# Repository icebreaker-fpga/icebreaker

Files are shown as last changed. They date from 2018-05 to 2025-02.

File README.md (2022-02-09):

# iCEBreaker FPGA

 

The iCEBreaker FPGA board is a low cost, open-source educational FPGA
development board.

The main motivating application of this board is for classes and workshops
teaching the use of the open source FPGA design flow using
[Yosys](http://www.clifford.at/yosys/),
[nextpnr](https://github.com/YosysHQ/nextpnr),
[icestorm](http://www.clifford.at/icestorm/),
[iverilog](http://iverilog.icarus.com/),
[symbiflow](https://github.com/SymbiFlow) and others. This means the board has
to be low cost and have a nice set of features to allow for the design of
interesting classes and workshop exercises. At the same time we want to allow
the user to use the proprietary vendor tools if they choose to. Because of that
we need to be compatible with their firmware upload tools.

## iCEBreaker Hardware Specifications

* iCE40UP5K in QFN48 (SG48) package
  * [iCE40 UltraPlus 5K](http://www.latticesemi.com/-/media/LatticeSemi/Documents/DataSheets/iCE/iCE40-UltraPlus-Family-Data-Sheet.ashx)
  * 5280 Logic Cells (4-LUT + Carry + FF)
  * 128 KBit Dual-Port Block RAM
  * 1 MBit (128 KB) Single-Port RAM
  * PLL, Two SPI and two I2C hard IPs
  * Two internal oscillators (10 kHz and 48 MHz)
  * 8 DSPs (16x16 multiply + 32 bit accumulate)
  * 3x 24mA drive and 3x hard PWM IP

* QSPI-DDR-capable flash 128 MBit (16 MB)
  * We selected to use the Winbond
    [W25Q128JVSIM](http://www.winbond.com/resource-files/w25q128jv_dtr%20revc%2003272018%20plus.pdf)
  * We want to enable projects that access the flash and we want to provide the
    highest flash access speed possible.

* [FT2232H](http://www.ftdichip.com/Support/Documents/DataSheets/ICs/DS_FT2232H.pdf) interface (microUSB plug)
  * programming compatible with iCEstick and HX8K board
    * works with [Dimond Programmer](http://www.latticesemi.com/programmer) and
      [iceprog](https://github.com/cliffordwolf/icestorm/tree/master/iceprog)
  * serial port compatible with iCEstick and HX8K breakout board
  * 12 MHz XTAL oscillator (shared with FPGA)
  * Solder jumpers to offer direct SRAM programming (like on HX8K breakout board)

* 39 I/O capable pins:
  * 4 pins for config (SDI, SDO, SCK, CSB)
    * Either loading config from on board FLASH chip or provided through the
      FTDI chip with direct SRAM config.
  * 2 extra GPIO pins for QSPI
    * Together with the config pins, allows storage of additional data in the
      FLASH chip, and high speed QSPI DDR access. For example
      [picosoc](https://github.com/cliffordwolf/picorv32/tree/master/picosoc)
      firmware.
  * 3 PINs for RGB LED (pin header)
  * 2 LEDs (one on output-only PLL pin)
  * 1 Clock pin (on PLL GBIN)
  * 1 UART Rx Pin via FTDI
  * 1 UART Tx Pin via FTDI
  * 1 Push Button
  * 16 PINs on dual PMOD
  * 8 PINs on single PMOD / snap-off section

* Support for FTDI Async FIFO mode
  * We want to support FTDI Async mode via some (unpopulated by default) zero
    ohm resistors
  * This shares 8 GPIOs with the single PMOD / snap-off section
  * This would also enable use of full list of RS232 signals
  * BDATA[0] -- Tx on FTDI / Rx on FPGA (always connected, no zohm resistor
    required)
  * BDATA[1] -- Rx on FTDI / Tx on FPGA (always connected, no zohm resistor
    required)
  * BDATA[7:2] -- Shared with snap-off section (via zohm resistor footprint)
  * RX Full -- Shared with snap-off section (via zohm resistor footprint)
  * TX Empty -- Shared with snap-off section (via zohm resistor footprint)
  * Read -- Shared with LED 1 (via zohm resistor footprint, LED used as RX
    indicator)
  * Write -- Shared with LED 2 (via zohm resistor footprint, LED used as TX
    indicator)
  * WakeUp -- Shared with Push Button (via zohm resistor footprint)
  * This configuration uses the following pins when the jumpers ore reconfigured:
    * The two on board red and green LED pins
    * The on board user button pin
    * snap off section single PMOD pins 

* Snap-off section (convertible to PMOD host / PMOD device)
  * 5 LEDs in similar arrangement to iCEstick
  * 3 Push Buttons

* Other stuff
  * Status LEDs for Power and CDONE (Configuration DONE)
  * Header with supply rails: 5V, 3V3, 1V2, GND
  * Debug header for all 6 QSPI pins
  * Test points for UART Rx / Tx signals
  * Jumpers or zohm resistors on all rails for measuring currents
  * Four 3mm mounting holes on the main section and two more on the snap-off
    section
  * The two LEDs on the main section should be wired "active low" so they work 
    well as indicator LEDs for FIFO read/write.
  * The five LEDs on the snap-off section should be wired "active high"
  * A zohm resistor for Bank 2 supply so that the IO voltage can be changed. Use
    Bank 2 for one of the ports on the double PMOD.
  * There should be auxilary 5V pin headers available for the PMODs. Some PMOD
    need either higher voltage or need to regulate their own voltage from 5V.

* Unpopulated parts shipped with the board
  * 3x Host PMOD (2x for dual PMOD port, 1x for snap-off section)
  * 1x Device PMOD (for other side of snap-off section)

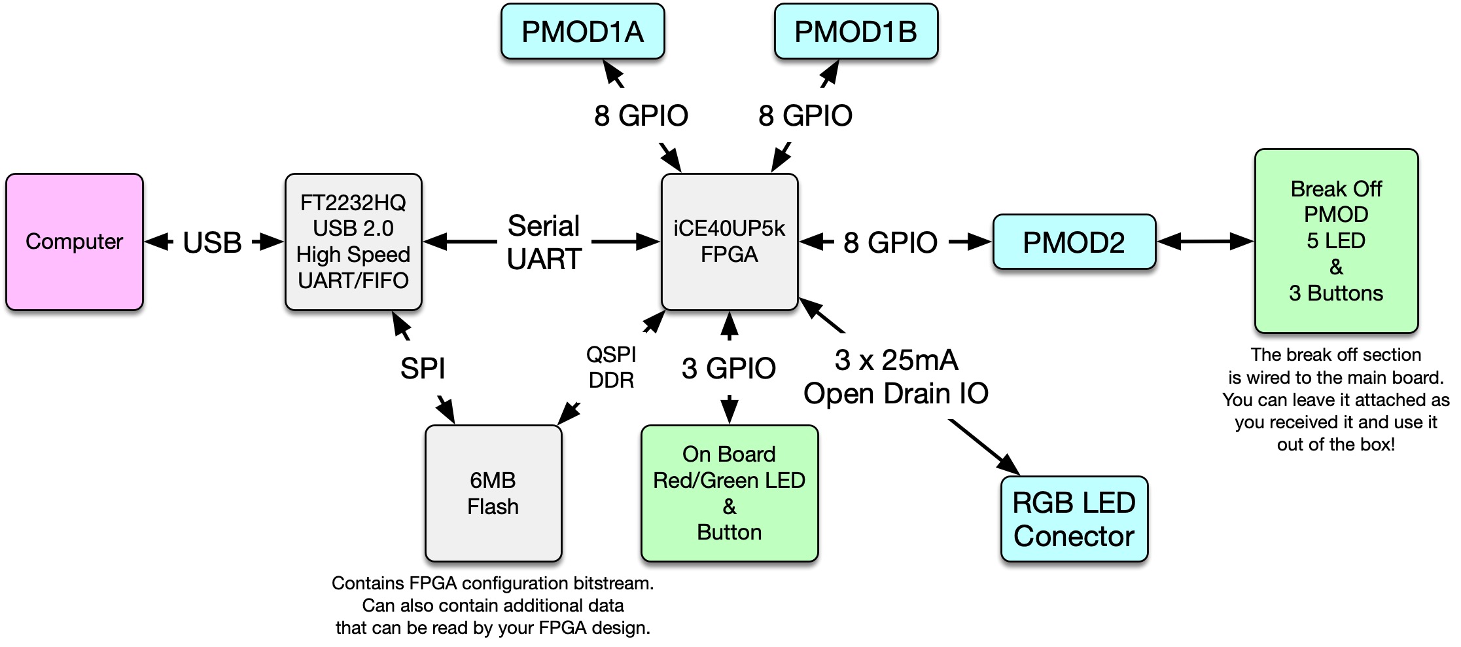
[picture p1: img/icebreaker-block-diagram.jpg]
iCEBreaker block diagram

**iCEBreaker block diagram**  
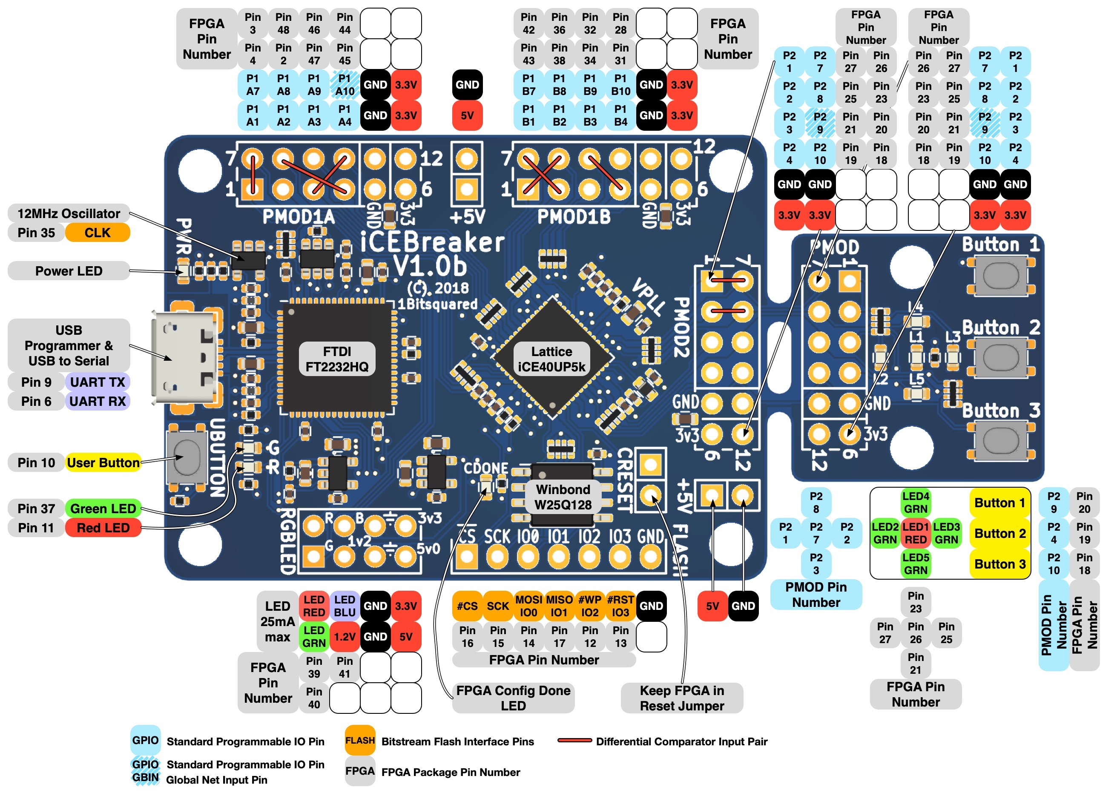
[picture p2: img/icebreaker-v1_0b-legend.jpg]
iCEBreaker V1.0b pinout legend

**iCEBreaker V1.0b pinout legend**  
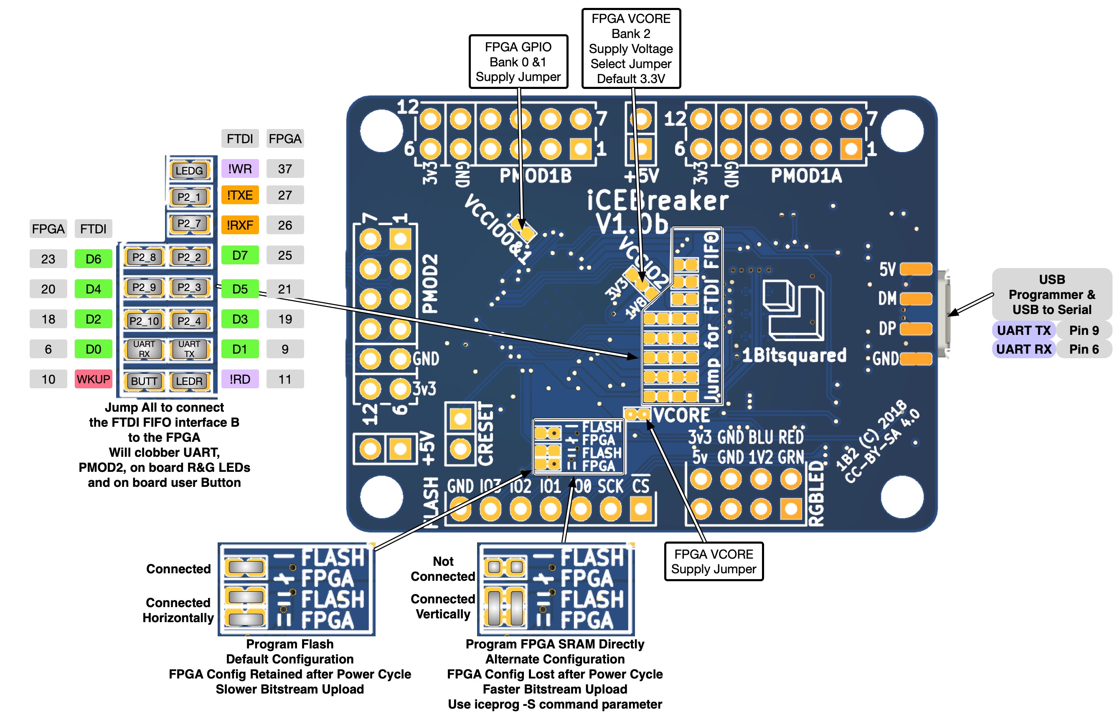
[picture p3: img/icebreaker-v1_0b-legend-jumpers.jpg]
iCEBreaker V1.0b jumper legend

**iCEBreaker V1.0b jumper legend**  

## iCEBreaker Bitsy

iCEBreaker Bitsy is the smaller but just-as-capable sibling to iCEBreaker. At just 36x18mm, it is compatible with the Teensy form-factor and can be easily embedded into any project.

iCEBreaker Bitsy v1.1b panel photo

* iCE40UP5K in QFN48 (SG48) package
  * PLL, two SPI and two I2C hard IPs
* 128M (16MiB) DDR- and QPI-capable Flash Memory
* 64M (8MiB) QPI-capable Pseudo-SRAM
* USB-C interface (comes preloaded with a [RISC-V soft-core USB bootloader](//github.com/no2fpga/no2bootloader))
* RGB LED connected to 3x 24mA hard PWM IP pins
* Two user LEDs (one shared with RAM-CS)
* Status LED for CDONE (Configuration DONE)
* 12MHz external clock (on PLL GBIN)
* One user button
* Supply rails: 3.3V and 1.2V
* FPGA SPI/programming header
  * 4 pins for config (SDI, SDO, SCK, CS)
  * 2 extra GPIO pins for QSPI/QPI
  * CDONE (Configuration DONE), CRESET (Configuration RESET), 3.3V, and GND
* Teensy form-factor compatible
* Compatible with Feather ecosystem using a [Teensy 3.x Feather Adapter](//adafruit.com/product/3200)
* Castellated edges and single-side-load for easy module integration

iCEBreaker Bitsy v1.1c info card, front
iCEBreaker Bitsy v1.1c info card, back

## Branding

[iCEbreaker](https://twitter.com/AboveVacant/status/948323920595308545)

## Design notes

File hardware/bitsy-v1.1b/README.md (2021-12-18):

# iCEBreaker Bitsy v1.1b

[Available at 1BitSquared](//1bitsquared.com/collections/fpga/products/icebreaker-bitsy)

iCEBreaker Bitsy is the smaller but just-as-capable sibling to iCEBreaker. At just 36x18mm, it is compatible with the Teensy form-factor and can be easily embedded into any project.

iCEBreaker Bitsy v1.1b panel photo

## Features
  
* iCE40UP5K in QFN48 (SG48) package
  * PLL, two SPI and two I2C hard IPs
* 128M (16MiB) DDR- and QPI-capable Flash Memory
* 64M (8MiB) QPI-capable Pseudo-SRAM
* USB-C interface (comes preloaded with a [RISC-V soft-core USB bootloader](//github.com/no2fpga/no2bootloader))
* RGB LED connected to 3x 24mA hard PWM IP pins
* Two user LEDs (one shared with RAM-CS)
* Status LED for CDONE
* 12MHz external clock (on PLL GBIN)
* One user button
* Supply rails: 3.3V and 1.2V
* FPGA SPI/programming header
  * 4 pins for config (SDI, SDO, SCK, CS)
  * 2 extra GPIO pins for QSPI/QPI
  * CDONE, CRESET, 3.3V, and GND
* Teensy form-factor compatible
* Compatible with Feather ecosystem using a [Teensy 3.x Feather Adapter](//adafruit.com/product/3200)
* Castellated edges and single-side-load for easy module integration

iCEBreaker Bitsy v1.1b info card, front
iCEBreaker Bitsy v1.1b info card, back

## Changelog

### v1.1b (2020-10-19)

* Changed board dimensions to metric instead of imperial (36x18mm)
* Added top-side silkscreen labels
* Enlarged USB-C solder paste openings

### v1.1a (2020-08-05)

* Switched to WSON 6x5mm flash to accommodate through-hole programming header
* Improved silkscreen

### v1.0a (2020-06-10)

* Complete redesign
* Pinout/dimensions now Teensy-compatible
* Moved Pseudo-SRAM to the top, populate it by default

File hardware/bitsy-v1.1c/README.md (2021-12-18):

# iCEBreaker Bitsy v1.1c

[Available at 1BitSquared](//1bitsquared.com/collections/fpga/products/icebreaker-bitsy)

iCEBreaker Bitsy is the smaller but just-as-capable sibling to iCEBreaker. At just 36x18mm, it is compatible with the Teensy form-factor and can be easily embedded into any project.

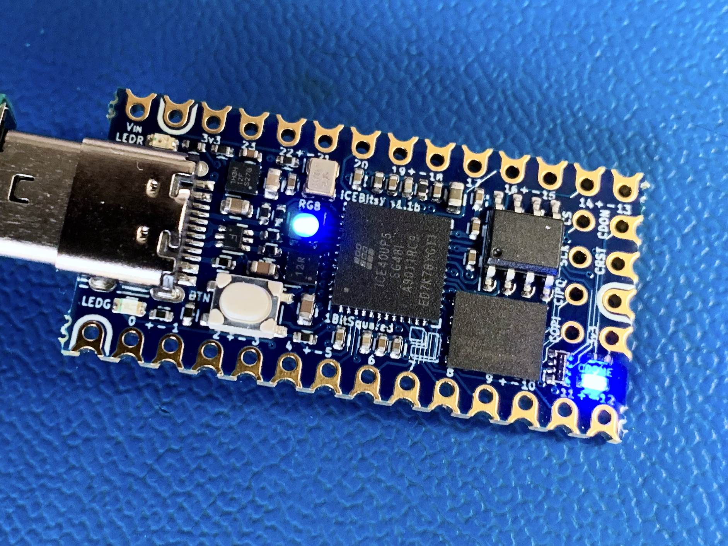
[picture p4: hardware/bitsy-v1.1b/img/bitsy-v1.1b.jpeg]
iCEBreaker Bitsy v1.1b photo


## Features
  
* iCE40UP5K in QFN48 (SG48) package
  * PLL, two SPI and two I2C hard IPs
* 128M (16MiB) DDR- and QPI-capable Flash Memory
* 64M (8MiB) QPI-capable Pseudo-SRAM
* USB-C interface (comes preloaded with a [RISC-V soft-core USB bootloader](//github.com/no2fpga/no2bootloader))
* RGB LED connected to 3x 24mA hard PWM IP pins
* Two user LEDs (one shared with RAM-CS)
* Status LED for CDONE
* 12MHz external clock (on PLL GBIN)
* One user button
* Supply rails: 3.3V and 1.2V
* FPGA SPI/programming header
  * 4 pins for config (SDI, SDO, SCK, CS)
  * 2 extra GPIO pins for QSPI/QPI
  * CDONE, CRESET, 3.3V, and GND
* Teensy form-factor compatible
* Compatible with Feather ecosystem using a [Teensy 3.x Feather Adapter](//adafruit.com/product/3200)
* Castellated edges and single-side-load for easy module integration

iCEBreaker Bitsy v1.1c info card, front
iCEBreaker Bitsy v1.1c info card, back

## Changelog

### v1.1c (2021-06-28)

* Added solder pads for USB-C SBU and CC pins
* Improved back side silkscreen

### v1.1b (2020-10-19)

* Changed board dimensions to metric instead of imperial (36x18mm)
* Added top-side silkscreen labels
* Enlarged USB-C solder paste openings

### v1.1a (2020-08-05)

* Switched to WSON 6x5mm flash to accommodate through-hole programming header
* Improved silkscreen

### v1.0a (2020-06-10)

* Complete redesign
* Pinout/dimensions now Teensy-compatible
* Moved Pseudo-SRAM to the top, populate it by default

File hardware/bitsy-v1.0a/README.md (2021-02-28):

# iCEBreaker Bitsy v1.0a

[Available at 1BitSquared](//1bitsquared.com/collections/fpga/products/icebreaker-bitsy)

iCEBreaker Bitsy is the smaller but just-as-capable sibling to iCEBreaker. At just 1.4x0.7in, it is compatible with the Teensy form-factor and can be easily embedded into any project.

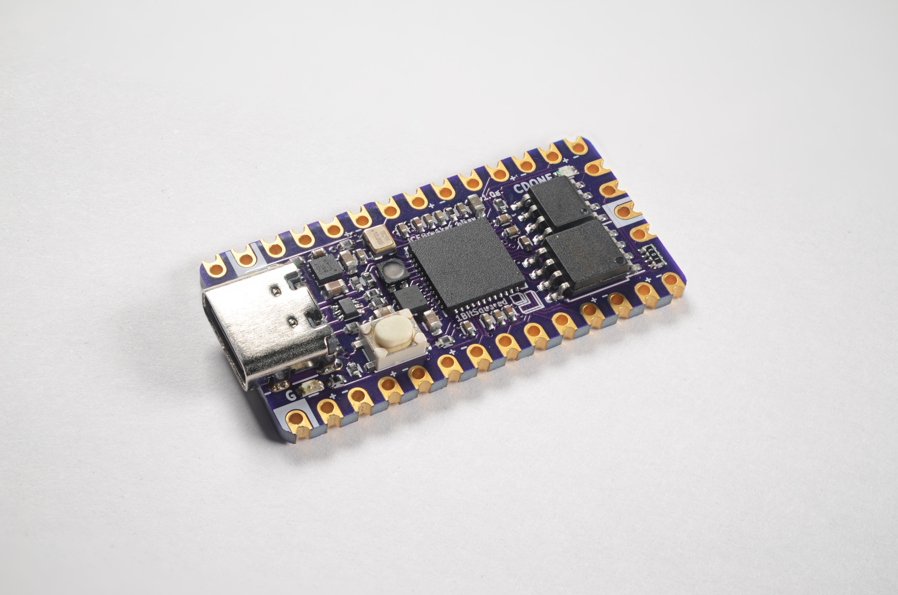
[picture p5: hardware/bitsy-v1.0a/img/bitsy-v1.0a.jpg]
iCEBreaker Bitsy v1.0a product photo


## Features

* iCE40UP5K in QFN48 (SG48) package
  * PLL, two SPI and two I2C hard IPs
* 128M (16MiB) DDR- and QPI-capable Flash Memory
* 64M (8MiB) QPI-capable Pseudo-SRAM
* USB-C interface (comes preloaded with a [RISC-V soft-core USB bootloader](//github.com/no2fpga/no2bootloader))
* RGB LED connected to 3x 24mA hard PWM IP pins
* Two user LEDs (one shared with RAM-CS)
* Status LED for CDONE
* 12MHz external clock (on PLL GBIN)
* One user button
* Supply rails: 3.3V and 1.2V
* FPGA SPI/programming header
  * 4 pins for config (SDI, SDO, SCK, CS)
  * 2 extra GPIO pins for QSPI/QPI
  * CDONE, CRESET, 3.3V, and GND
* Teensy form-factor compatible
* Compatible with Feather ecosystem using a [Teensy 3.x Feather Adapter](//adafruit.com/product/3200)
* Castellated edges and single-side-load for easy module integration

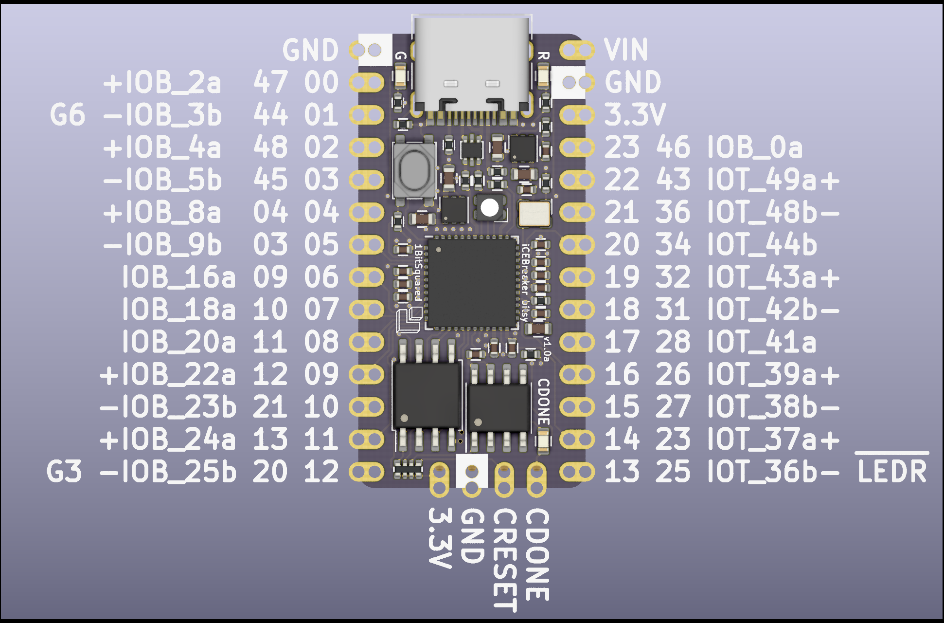
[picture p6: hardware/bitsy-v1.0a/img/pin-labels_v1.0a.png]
iCEBreaker Bitsy v1.0a pin labels, top

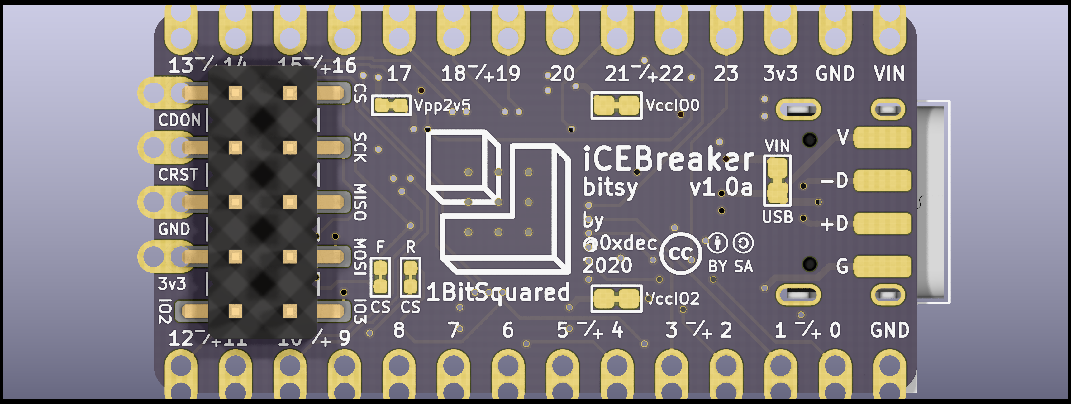
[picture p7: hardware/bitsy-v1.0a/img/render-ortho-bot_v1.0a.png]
iCEBreaker Bitsy v1.0a render, bottom


## Changelog

### v1.0a (2020-06-10)

* Complete redesign
* Pinout/dimensions now Teensy-compatible
* Moved Pseudo-SRAM to the top, populate it by default

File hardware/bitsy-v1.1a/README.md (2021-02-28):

# iCEBreaker Bitsy v1.1a

[Available at 1BitSquared](//1bitsquared.com/collections/fpga/products/icebreaker-bitsy)

iCEBreaker Bitsy is the smaller but just-as-capable sibling to iCEBreaker. At just 1.4x0.7in, it is compatible with the Teensy form-factor and can be easily embedded into any project.

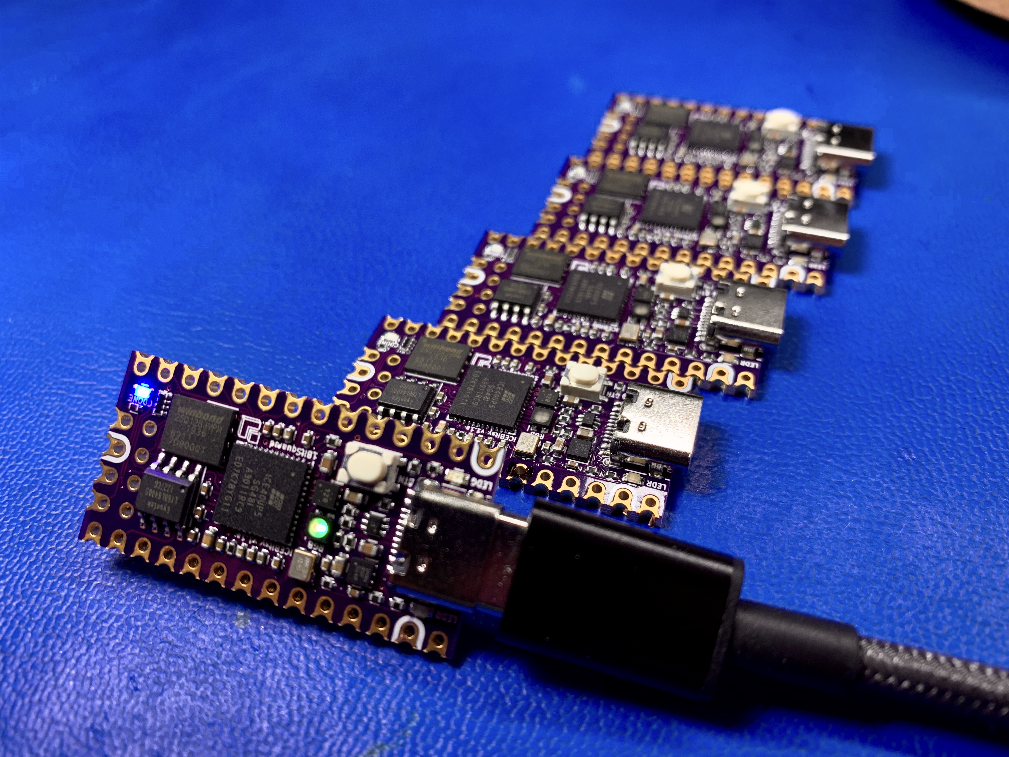
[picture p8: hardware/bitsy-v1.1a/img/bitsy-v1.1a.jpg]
iCEBreaker Bitsy v1.1a photo


## Features

* iCE40UP5K in QFN48 (SG48) package
  * PLL, two SPI and two I2C hard IPs
* 128M (16MiB) DDR- and QPI-capable Flash Memory
* 64M (8MiB) QPI-capable Pseudo-SRAM
* USB-C interface (comes preloaded with a [RISC-V soft-core USB bootloader](//github.com/no2fpga/no2bootloader))
* RGB LED connected to 3x 24mA hard PWM IP pins
* Two user LEDs (one shared with RAM-CS)
* Status LED for CDONE
* 12MHz external clock (on PLL GBIN)
* One user button
* Supply rails: 3.3V and 1.2V
* FPGA SPI/programming header
  * 4 pins for config (SDI, SDO, SCK, CS)
  * 2 extra GPIO pins for QSPI/QPI
  * CDONE, CRESET, 3.3V, and GND
* Teensy form-factor compatible
* Compatible with Feather ecosystem using a [Teensy 3.x Feather Adapter](//adafruit.com/product/3200)
* Castellated edges and single-side-load for easy module integration

iCEBreaker Bitsy v1.1a info card, front
iCEBreaker Bitsy v1.1a info card, back

## Changelog

### v1.1a (2020-08-05)

* Switched to WSON 6x5mm flash to accommodate through-hole programming header
* Improved silkscreen

### v1.0a (2020-06-10)

* Complete redesign
* Pinout/dimensions now Teensy-compatible
* Moved Pseudo-SRAM to the top, populate it by default

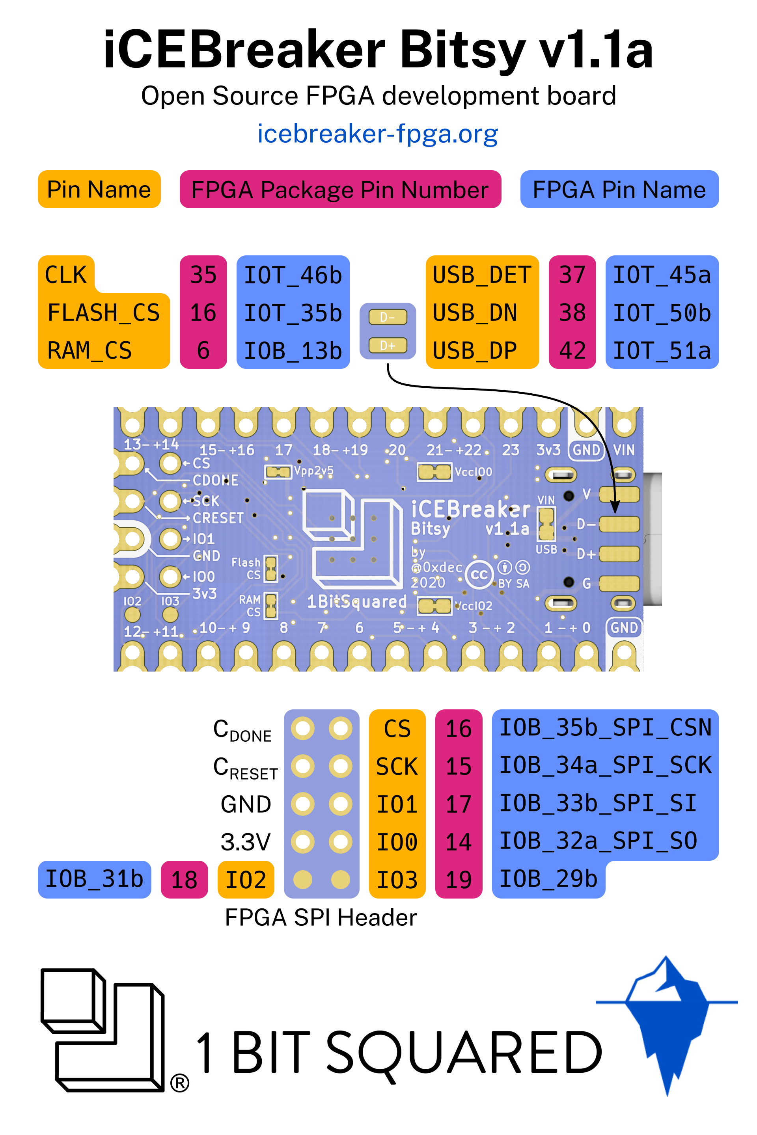
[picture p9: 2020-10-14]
hardware/bitsy-v1.1a/img/bitsy-v1.1a-info-card-bot.png

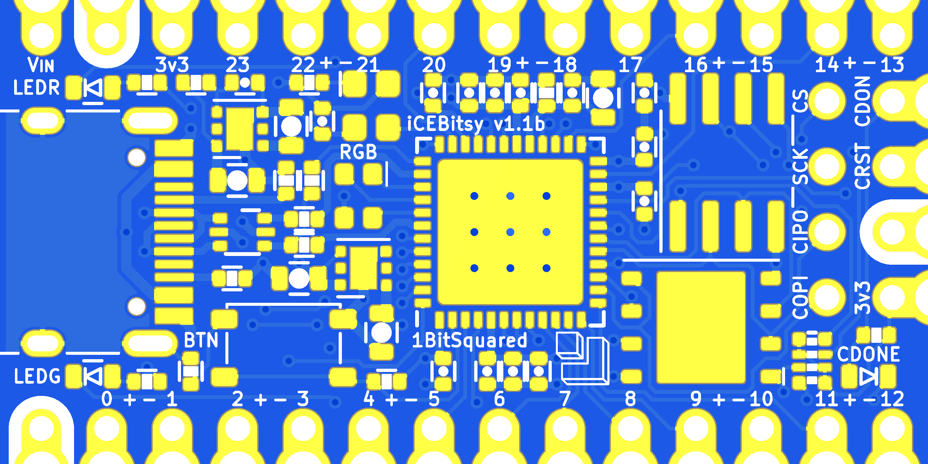
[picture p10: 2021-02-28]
hardware/bitsy-v1.1b/img/bitsy-v1.1b_bare_front.png

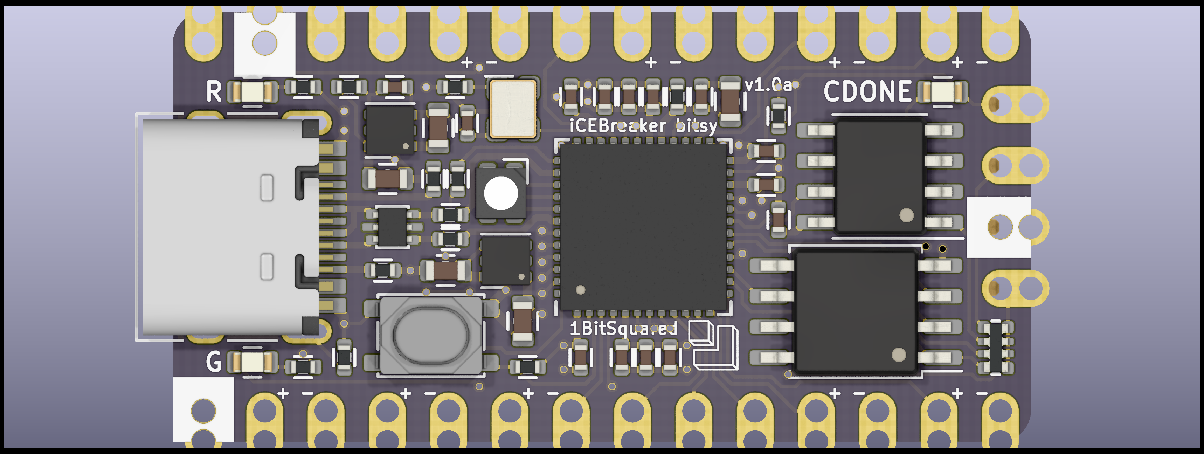
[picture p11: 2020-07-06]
hardware/bitsy-v1.0a/img/render-ortho-top_v1.0a.png

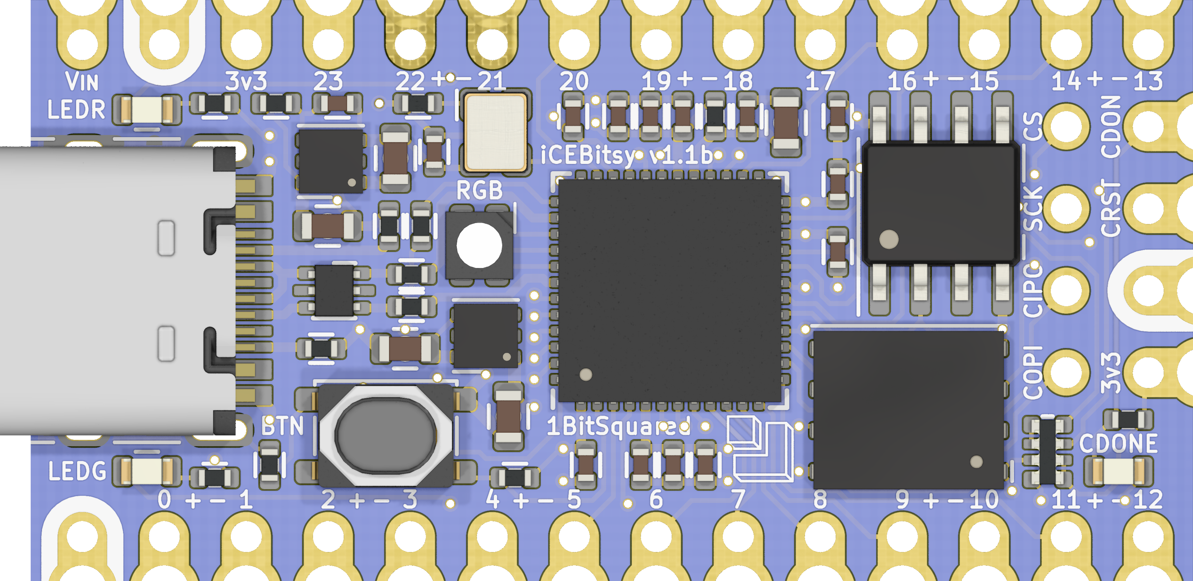
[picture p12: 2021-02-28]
hardware/bitsy-v1.1b/img/bitsy-v1.1b_render_front.png

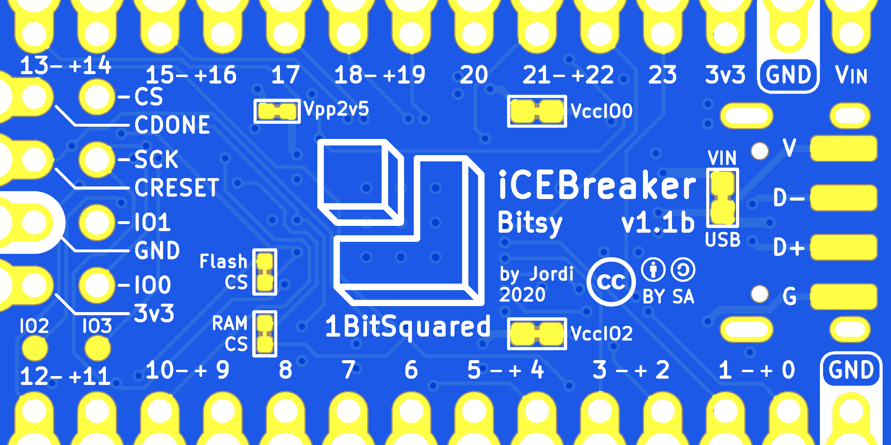
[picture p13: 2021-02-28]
hardware/bitsy-v1.1b/img/bitsy-v1.1b_bare_back.png

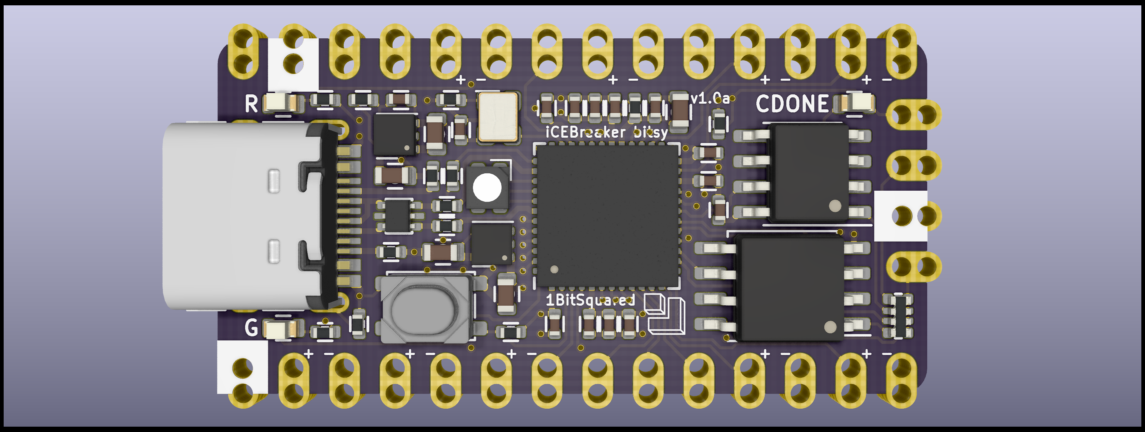
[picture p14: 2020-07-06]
hardware/bitsy-v1.0a/img/render-top_v1.0a.png

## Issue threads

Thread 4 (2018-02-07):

Replace 0402 4.7uF capacitors with 0603

esden, 2018-02-07:
On the iCEBreaker v0.1a we are using a mix of 0402 and 0603 footprints for 4.7uF capacitors. This does not seem really necessary as we seem to have enough space on the iCEBreaker full size board. There is no need to use two sizes of the same value parts.

Closed 2018-03-05.

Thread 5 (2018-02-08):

Add slewrate limiting IO resistors

esden, 2018-02-08:
Based on input from @mubes and @markusbec we should consider putting in some inline resistors for all the FPGA IO pins. This is necessary to allow for high speed communications.

esden, 2018-03-11:
Partially fixed (for icebreaker) in commit 398d212c9b70fa2c4f8a7f37c95a3dc61060f905

esden, 2018-03-11:
Due to lack of space I decided to postpone adding the slew rate resistors to the bitsy version of icebreaker. Closing this Issue for now.

Closed 2018-03-11.

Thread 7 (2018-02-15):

Can you add HyperRam ?

mirecta, 2018-02-15:
I have an idea:
Add HyperBus RAM (selfrefresh DRAM) to design, its small, cheap, low pin count but enough fast , and enough space (8 or 16MB)
S27KL0641 or S27KS0641
http://www.cypress.com/products/hyperram-memory
https://www.digikey.com/en/product-highlight/c/cypress/hyperram-memory

it will be good for image prcessing/buffering etc.

cliffordwolf, 2018-02-15:
- Which pins would you use for this? I.e. which other feature(s) would you drop to make space for those pins? (see icebreaker-sch.pdf)
- Why is a PMOD with HyperRam on it not sufficient for those use cases? Why does it need to be on the board?

daveshah1, 2018-02-15:
IMO if onboard RAM is a very frequent request the only feasible option is QSPI PSRAM (like the ESP32 uses), this could have data lines shared with flash and would only need one extra IO (CS).

mirecta, 2018-02-16:
This HyperRam uses OctoSPI similar QSPI i thing pins may be shared as wrote daveshah1

mirecta, 2018-02-16:
QSPI would be a good idea too , any low pin serial psram

esden, 2018-02-16:
First thank you for your interest in iCEBreaker! I do appreciate that. But we have to consider any feature addition, especially one that will change the current board feature set and cost, very carefully.

From the feature perspective. I am not convinced that having HyperRAM on every board is such a core feature that everyone would need it and use it. HyperRAM can be added as a PMOD for those that need it. On the other hand I know that having additional RAM will be useful for a variety of applications.

Adding Hyperram even when reusing the FLASH pins is not possible without giving up some signal on the board. It will at least require an additional Chip Select signal. There is no free lunch here. Before you suggest things like that make sure to look at the schematic. __ALL__ pins have currently functions assigned. We even have double pin assignment using jumpers on the board. So as @cliffordwolf said, please make an argument based on the current schematic and think about which function we would have to give up to get that one additional signal. That would be even worse if we wanted OctoSPI... where do you want to steal another 4 signals?

Another reason to use HyperRam on the PMOD connector instead of reusing the FLASH pins is that then you can use Hyperram simultaneously with the FLASH.

Last but not least we also have the increased cost of the overall board when adding another chip and passives to the board. You are proposing of a retail price increase of almost $10 per board. Yes that is how part and assembly cost to retail cost translations work unfortunately... are you sure that everyone who is the potential user will see the hyperram as such a great feature that they will be willing to spend an additional $10 on it?

That said you will have to provide me with more reasons than just "I would like to have it" as that is not enough of a reason and "I feel like it is easy to do" because it is not.

All that is in the framework of the pure iCEBreaker. We could consider a separate version of the board that has Hyperram on board, but for that we have to still figure out what feature we want to drop to enable on board Hyperram. If you can figure out how to add the Hyperram with minimal impact to the current featureset of the iCEBreaker I still would like to hear about it.

cliffordwolf, 2018-02-16:
I don't see how we can add the signals for HyperRAM. We just don't have the extra pins for the wider interface.

But I like @daveshah1's idea of supporting QSPI PSRAM. We could add a footprint compatible with SOIC-8 and SOIC-8-N to the backside of the board and use ~BUTTON as chip select for the footprint and share the other pins with the main flash.

That would allow users to add another flash or serial RAM at the cost of the button. We would not have extra cost because it's an unpopulated part. This scheme would even work with the FTDI FIFO because xFIFO_WKUP is an optional signal in the FT2232H Async FIFO protocol.

daveshah1, 2018-02-16:
Although it seemed like a good idea, for some reason none of the main distributors seem to carry any decent QSPI PSRAM parts - despite there being several manufacturers in China/Taiwan of it, so it may not be feasible.

The ideal part would be the LY68L6400, which is 64Mbit 3.3V SQI, up to 33MHz normal/100MHz fast reads. However despite some tantalising photos and forum posts of people who have it, it doesn't seem to be available anywhere, even Taobao - the usual source for these obscure things.

The other option that came to mind was the part ESP make for their ESP32, the ESP-PSRAM32, which is 32Mbit, but only 1.8V, so would complicate things significantly.

Maybe it's still worth considering the footprint, the parts may become more available, or it may be a case of biting the bullet and buying a reel from the manufacturer if there's enough interest.

smunaut, 2018-11-04:
The LY68L6400 is in stock at LCSC :)

Even if no footprint is added or for previous revision of the board, it should be fairly easy to add ... just solder it above the flash chip and use a wire to route the CS_n pin to the right place.

mithro, 2018-11-04:
There is a hyperram dual pmod board which should work on the icebreaker. Does mean you are down to a single pmod for other things.

smunaut, 2018-11-04:
@mithro Yes. I was also considering making a single  PMOD hyperram by just dropping 4 data bits ... (and given the DDR nature, you'd still have 8 bits per clock which is not unnatural).

smunaut, 2018-11-04:
Never mind, it's a stupid idea ... you also need to send commands through that bus ... doh ... too early in the morning :p

esden, 2018-11-05:
What we could do is put the unpapulated LY68L6400 footprint on the back of the board so that it can be added as an option, by the user. I don't think we have enough space on the front of the board for it. Still this might be a nice option. I would also use one of the on board LED lines to drive the RAM CS line. We can reconsider how things go together for the V2.0 of the iCEBreaker... ;)

esden, 2018-11-05:
I am closing this issue in favor of the #19 I think that this is the most reasonable path forward.

Closed 2018-11-05.

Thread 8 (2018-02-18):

Add USB breakout pads

esden, 2018-02-18:
We need to add easily accessible USB pads on the reverse side of the iCEBreaker. At least on the bitsy version of the board. The pads should be similar if not the same as the ones on the 1Bitsy boards. It will make debugging of the @tinyfpga bootloader much easier, and allow the user to solder in a USB cable if necessary.

esden, 2018-03-11:
Partially fixed in 4fe2328cd23c2c67c4ea3d756215ce9fffbe3354 for the full sized icebreaker. That one still has an FTDI chip on board so these pads are mostly used for testing and hard wiring extension cables.

Closed 2018-03-11.

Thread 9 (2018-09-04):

Add jumper for CRESET

cliffordwolf, 2018-09-04:
Please add the following feature:

- A (10k?) resistor between `CRESET_B` on the FPGA and `ADBUS7` on the FTDI.
- A (2-pin through hole) jumper that allows grounding of `CRESET_B`.

I would have needed that a few times now when writing designs that talk to the flash, or use the flash io pins. When the design puts the flash in state where it is not responsive anymore, you need to find a way of preventing the FPGA from booting on power up or you cant reprogram the flash anymore.

Closed 2018-09-06.

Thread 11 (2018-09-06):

Remove bypass of the VCCIO2 jumper.

esden, 2018-09-06:
It turns out I have missed the fact that the VCCIO2 supply jumper is actually connected to the 3v3 rail on the internal power plane. This is caused by using normally open jumpers to create normally closed ones. The two pads of the jumper are on the same net and it is easy to miss the fact that both pads are connected to 3v3.

Fix this by using normally closed jumpers that only connect two nets within the footprint and keep the connectivity algorithm out of the equasion using a line on copper layer within the footprint.

How to create such a footprint is described in the KiCAD forum: https://forum.kicad.info/t/creating-a-star-ground-component/3456/8

Close this issue when the problem is resolved.

Closed 2018-09-06.

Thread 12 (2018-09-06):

Mark the FTDI flash as optional/DNP

esden, 2018-09-06:
It turns out that we do not need to program the FTDI flash chip with anything. We can save a few placements and parts. Let's keep the footprints in case we find out that we need them in the future or the user decides to add that functionality for their own needs.

Close this issue when the schematic DNP fields are marked accordingly and the note about the circuit being optional is added to the schematic.

esden, 2018-09-10:
That is a good point regarding the serial numbers. I will open a new issue that adds the parts back in and asks for unique serial numbers on all boards.

Closed 2018-09-06.

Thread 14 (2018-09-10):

Explore the possibility of using a low cost STM32 instead of FTDI

esden, 2018-09-10:
There are very low cost STM32 that don't even require an external oscillator to be used with USB.

STM32F042K6 for example can be purchased on aliexpress for ~$1.50. I have also compared prices of similar parts from other vendors. The STM32 turns out to be lower cost than any alternative chip with this kind of specifications. With added bonus of being easily available from a lot of vendors on aliexpress.

List of advantages of the STM32:
* significantly lower cost: ~$15 lower retail cost of the icebreaker
* less parts and placements: no external flash chip and no external oscillator needed
* automatic unique serial number in the descriptor strings generated from the unique id of the STM32. No need to track unique serial numbers in manufacturing.
* flexible firmware on the STM32 alowing for updates and new features in the future
* Possible to wire up so that we don't need to use any jumpers to choose FLASH or FPGA flashing

List of disadvantages of the STM32:
* Need to develop firmware for the STM32
* Need to develop desktop program for flashing (multiplatform software developemnt)
* Mess with drivers depending on which model we use (windows headaches mostly)
* No high speed USB just full speed.
* No optional asynchronous FIFO mode.

List of things we retain:
* Ability to flash the on board FLASH chip
* Ability to upload bitstream to the FPGA directly
* Ability to connect to the UART serial port (USB to serial converter)
* Generate 12MHz external clock for the FPGA (STM32 MCO pin)

This issue is here to track the testing of that part. Close it if we decide not to go down that path, or we realize that it has some big flaw that is worth the 4x price difference of the FTDI chip. Or when we decide to use this approach and decide that this is our main path.

esden, 2018-09-10:
Added a list of alternative chips to the STM32.

I am still planing to continue down the road with STM32 as I know that chip family very well. They are abundant and easy to get from many sources. The price is comparable with the other chips. And I have many projects to source code from. Also STM32 is best supported by Black Magic Probe and I like to be able to be able to debug the things I build. :)

esden, 2018-09-10:
After a discussion with @cliffordwolf here is a collection of thoughts about how we want to build the USB interface on the device:

Requirements:
* Has to be easy to setup on all the major three OS, with no driver installation if possible:
  * Linux
  * Windows
  * MacOS X
* Has to have a simple protocol but preferably not bitbang as it is super inefficient
* Provide FLASH programming (SPI)
* Provide USB-Serial for simple FPGA designs (UART) (this is much simpler than adding a full USB stack to the design that is why an external chip is being considered at all)
* The programming protocol has to support the following features:
  * Flash the SPI FLASH containing the FPGA bitstream
  * Upload bitstream directly to the FPGA SRAM cells
  * Reset FPGA
  * Reset FLASH and get it out of QSPI mode for flashing

Resulting design decisions:
* Due to how ugly Windows driver situation is we prefer to use a builtin virtual serial driver instead of going raw libusb protocol.
* The device presents the following hybrid USB interface to the PC:
  * CDC-ACM (Virtual Serial) port No. 1 for FPGA flashing
  * CDC-ACM (Virtual Serial) port No. 2 for USB-Serial adapter interface
  * DFU stub, gives access to the DFU bootloader of the STM32 for programmer firmware upgrade.
* Base the programming protocol on the FTDI MPSSE engine opcodes. This way adding support for this programmer to iceprog will be relatively simple. How viable this is, depends on how much extra functionality we will want to add that is currently not possible with the FTDI programmer solution.

mithro, 2018-09-10:
FYI - You can perfectly emulate a FTDI chip with these low cost STM32 chips
(just a matter of software :-)

On Mon., 10 Sep. 2018, 3:02 pm Piotr Esden-Tempski, <
notifications@github.com> wrote:

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

esden, 2018-09-10:
@mithro I bet this is possible. I am not sure what benefit it provides besides the direct reuse of existing programmer desktop software. I do like the idea, it might be either the default or an alternate use of the stm32 programmer.

What I like even more is to be able to do things that the FTDI chip does not provide. For example being able to program the flash chip or the FPGA sram directly without having to set jumpers. Having a feature like this would somewhat offset the loss of high speed USB and FIFO modes.

mithro, 2018-09-11:
@esden Emulating the FTDI chip is kind of silly -- except it stops people complaining about you not using the FTDI chip.....

ekawahyu, 2018-10-02:
@esden what would be the USB library you have in mind? I did some code with STM32 library for CDC-ACM and DFU capability on F072. It was like 48kB+, so probably it won't fit in F042K6T6. It was compiled with GCC, it would probably much less with paid compilers.

gsteiert, 2018-10-03:
How about MSC with UF2 instead of DFU?
There is an STM port:
https://github.com/mmoskal/uf2-stm32f
It really simplifies the windows driver issues and you don't have compile a programming app for every OS.

mithro, 2018-10-03:
I agree that having support for UF2 would be excellent.

The great thing about having an ARM micro is that you could potentially support *all* these modes. UF2, DFU, FTDI serial, etc.... It's just different software code running on the microprocessor.

UweBonnes, 2018-11-08:
The FT2232H allows to pump data to the PC with up to 30 MByte/s. Some Full-Speed device like the STM32F042 can only do up to 1.5 MByte/sec...

osterwood, 2018-11-08:
The ATSAMG55 looks promising.  The G package gets down to $2.92 in QTY 1k when purchased direct from Microchip.  Impressive specifications and have USB HS.  SKUs are:

* ATSAMG55J19A
* ATSAMG55J19B
* ATSAMG55G19A
* ATSAMG55G19B

G are 49/WLCSP package and J are 64/LQFP (they are a little more expensive).  I've never used them before, but might be worth considering.

esden, 2018-11-08:
@osterwood are you sure they have USB HS? From the datasheets it seems they only have a FullSpeed transceiver built in. But I might be missing something. There are plenty of ARM Cortex chips that have HighSpeed support but require an external PHY. I was hoping to avoid that.

UweBonnes, 2018-11-08:
STM32F723 has HS Phy on chip, but pricey also...

osterwood, 2018-11-08:
Yeah - you're right.  Saw "high speed" on the summary page and just assumed.  Looks like the only options from Microchip are PIC32MZ ($6 to $7) and SAMS7x/E7x/V7x ($5 and up)

mithro, 2018-11-08:
If you want full 480 megabit, the FX2 chip is a decent option and can get down to $3-4 USD each. They are used on our Opsis and Atlys board.

@whitequark has been working on doing FX2 firmware to support UF2, Serial and DFU programming modes for me.

UweBonnes, 2018-11-09:
The STM32F730Z8T6 (with integrated OTG HS phy) comes need to the 3$@1000 margin.
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
zeroeth, 2019-09-22:
A little late to the party, but just want to +1 stm32 because of all the great libopencm3 examples/workflows.

Having the board potentially be dual purpose (and custom usb hid such as usb joystick/midi) would be absolutely jawesome.

related: dadamachines did something similar so the board is directly arduino compatible too https://dadamachines.com/product/doppler/ some food for thought! Especially now that arduino themselves have a mostly closed toolchain fpga hybrid board.

ejhollas, 2019-10-12:
Windows drivers can be simplified by making use of Microsoft's WinUSB drivers. These drivers are built-in to Windows 8 and later. A simple INF file can make it work on Windows 7 as well.

To get Windows to attach WinUSB, the ST firmware will just need a few USB descriptors that Windows will read on first plug-in. No drivers need signing using this method. WinUSB supports composite devices, so we can expose a CDC serial interface and a vendor specific interface. This will allow us to use high bandwidth endpoints over bulk or iso.

The WinUSB API has native C bindings. There is support in the libusb project as well as C#, go and python bindings. I'll be happy to help contribute and test the descriptors.

rljacobson, 2019-11-28:
I am curious to know if V2.0 is being actively developed, as there does not seem to be much activity on this issue. @majbthrd's experimentation seems to indicate that the Nuvoton chip is in some ways quirky but serviceable. The STM32F730Z8T6 has the advantage of familiarity, runs at twice the clock rate, but costs slightly more and has comparatively little FLASH ("external memory can be used with no performance penalty thanks to the L1 cache").

gsteiert, 2019-11-28:
I think there are a few new options since this thread was started.  The
i.MX RT1064 used on the Teensy 4.0 is even faster, or the RT1010 for a
lower cost option.  The LPC55xx series has integrated flash.  All of these
have the high speed USB phy integrated.

On Wed, Nov 27, 2019, 10:47 PM Robert Jacobson <notifications@github.com>
wrote:

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

UweBonnes, 2019-11-29:
Greg Steiert writes:
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
I see one problem in a missing USB HS stack that is open source and
works with a makefile

--
Uwe Bonnes                bon@elektron.ikp.physik.tu-darmstadt.de

Institut fuer Kernphysik  Schlossgartenstrasse 9  64289 Darmstadt
--------- Tel. 06151 1623569 ------- Fax. 06151 1623305 ---------

tannewt, 2019-11-29:
I'd like to add high speed support to [TinyUSB](https://github.com/hathach/tinyusb) (an open source USB stack). @hathach just added full speed support for the i.MX RT series.

hathach, 2019-11-29:
@tannewt thanks, iMX RT series is actually  highspeed USB :)

ulixxe, 2021-11-06:
Another possibility is to implement USB device stack on the same FPGA fabric. See:
https://github.com/ulixxe/usb_cdc

smunaut, 2021-11-06:
Did you even _read_ the thread ?

gregdavill, 2022-02-12:
There are now WCH parts available* that integrate a USB HS PHY. Like Gigadevices they have both CorteX-M3/RISCV variants, they also have some "RISC" based devices for implementing interface controllers, these appear to fill a similar market to the FX2 series, not sure if they're also

Here are some RISCV based options:
- CH565/CH569, USB2/3 with built in PHY. (Likely extra cost since you're paying for the USB3 PHY, when it's not needed)
- CH563, USB2 HS with built in PHY.
- CH32V305/307, USB2 HS with built in PHY.

Cortex M3 options:
- CH32F205/207, USB2 HS with built in PHY.

All of these also include USART+SPI so should satisfy the base requirements for interface to the FPGA.

LCSC has stock of the CH32V307, other parts I imagine you'll have to contact WCH for a sales channel, like Gigadevices.

The main downside these parts have is their size, because they also include a fair few extra interfaces the smallest parts are in LQFP-100/LQFP-64. So might end up making the board a bit dense.

psherman42, 2025-02-15:
Would really like to see a small basic board without any USB whatsoever, regardless FTDI or otherwise. Leave the host interface as an optional attachment to be decided by the user. In other words, modularize rather than integrate. There may be people out there, now or in future, wishing for a retro UART or RS-232 host link ...

fanoush, 2025-02-17:
> The main downside these parts have is their size, because they also include a fair few extra interfaces

I know this is old comment but recently I got some cheap CH32V305 based debug dongles and they work quite fine with HS mode when reflashed to  https://github.com/prosper00/CH32V305-DAPLink-HS  and the TSSOP20 part used there is not big.

The dongle is either WCH-Link E (about $5 on aliexpress) or there is mini version
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 for about $2.50

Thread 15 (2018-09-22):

Add Access to FT2232H VREGOUT +1V8 for Powering VCCIO2

RossBencina, 2018-09-22:
Greetings folks, I would like to make a suggestion. I can turn this into a PR if there is interest.

The FT2232H has as regulated 1.8V output. VCCIO2 provides a jumper for supplying a different IO voltage. Wouldn't it be nice if +1V8 could be optionally used to power VCCIO2? For example, there are a number of single board computers with 1.8V GPIO and I2S, it would be nice to be able to connect the icebreaker PMOD to them directly.

I believe that powering VCCIO2 from FT2232H VREGOUT would be compatible with the UP5K power sequencing requirements.

I can see two ways to make this happen:

1. Provide a test pad to allow greenwiring from the the pad to the jumper (see below)
2. Route +1V8 through one of the middle layers and provide a 3-way jumper for VCCIO2. (Replace J17 with a 3-way jumper). I have not tried this but it looks possible.

To show what I mean, for option (1) here is how it could work:

Add test point:
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

On F.Cu, add via to route +1V8 to B.Cu:
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

Add pad to B.Cu:
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

esden, 2018-09-23:
That is great! You are the second person to bring up the 1v8 supply. I was about to add a way to expose that net. The only thing I need to check is what the allowed load on that regulator inside the FTDI chip is. Also it would be nice to find a way to bring that power net closer to the jumpers. If you already have your changes done feel free to open a pull request. It could be a good starting point for me.

Thank you very much for the idea and the time! :)

RossBencina, 2018-09-27:
@esden Sorry, only just found time to get back to this. I've made a pull request with my Test Point changes, but I don't recommend that you merge it. The diff to icebreaker.kicad_pcb seems very large (maybe because I shoved some traces to place the test point).

As I said above, I think the best approach is to make a 3-way jumper for VCCIO2 and route the 1v8 signal  on the (middle) power plane.

I too haven't researched whether the FTDI can source enough current for this to be safe. And if you switch to STM MCU maybe this whole thing becomes moot.

@alexhude: so far this update is for VCCIO2 only. (Which is all I need ;) ) But maybe you can make a case for adding it to other ports?

Closed 2018-10-14.

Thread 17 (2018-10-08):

Adjust footprint to match new buttons

esden, 2018-10-08:
I have chosen better buttons for the icebreaker. They have a better feel and are more affordable.

The new button and footprint can be found on [Aliexpress](https://www.aliexpress.com/item/Free-Ship-100pcs-lot-SMD-3-4-2-5mm-4-pin-Push-Button-Switch-e-cigarette/32786905142.html).

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

They fit on the current footprint but it is not perfectly matching the pins of the new button.

Closed 2018-10-14.

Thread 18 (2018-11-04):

Add another CS line from FTDI to the iCE40 to use SPI comm from host -> fpga

smunaut, 2018-11-04:
Having SPI communication from host to the ice40 has many benefits :
 - Very simple protocol to implement (I'd say even simpler than UART since it's synchronous)
 - Can be clocked fast (Up to 30 MHz)
 - Re-use most of the existing pins used for the configuration.

The only thing needed is a way to differentiate between host accessing the flash and the host accessing the user logic in the fpga.

This can be done one of two ways :
* Using discrete logic gates. Since host access to the flash is only going to happen when CDONE is low (or CRESET is low), you can use single gate 74 logic to mask the CS signal to the flash.
However this solution at this stage is not ideal because :
   - Non trivial change to the design
   - Adds parts (and thus BOM cost and pick and place time and ...)
   - Interferes with access of fpga logic to the flash once booted.
* Use another distinct CS line from the FTDI to another iCE40 pin. Best candidates are the two leds signals LEDG / LEDR or the button signal. I like the LED signal because this way I still have one button and one led for user logic. And also the led blinks when there is SPI access from the host, providing a visual indicator of access.

So all in all, I think a solder jumper from LEDG to ADBUS3 would be a good idea.

esden, 2018-11-18:
I went with the ADBUS3 to LEGR solution. Cheers! :D

AnasMalas, 2025-01-09:
@esden
To clarify - in V1.0e, the jumper is connected by default, so I should avoid driving LEDR from the FPGA to avoid damage - as this is an output pin on the FTDI chip. Is this correct? If so, I think this should be included in the readme

Closed 2018-11-18.

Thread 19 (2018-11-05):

Add unpapulated QSPI RAM footprint

esden, 2018-11-05:
To add expanded RAM amount to the iCEBreaker without sacrificing the PMODs we should have an SO8 unpopulated/optional footprint for the LY68L6400.

We can think about a better setup for this in the V2.0 hardware cycle.

esden, 2018-11-18:
As per @smunaut suggestion. I have added a pad that allows for an easy addition of an SPI RAM chip in SO8 package piggybacked onto the existing flash chip. We can't use ram and flash at the same time but we can use them in the same design by using ~LEDG signal as CS for the RAM. It is good enough for V1.0 ;)

umarcor, 2020-12-17:
@esden, I can't identify that pad in the schematics or the figures in the readme. Was it removed in the end?

smunaut, 2020-12-17:
Next to pin 37 of the fpga in https://github.com/icebreaker-fpga/icebreaker/blob/master/hardware/v1.0e/icebreaker-sch.pdf

umarcor, 2020-12-17:
@smunaut thanks. I misunderstodd the meaning of "piggybacked" and I was looking for an unpopulated footprint at the bottom. All clear now.

esden, 2020-12-17:
@umarcor Right, it might not be clear for everyone. I am putting a photo of how it comes together for reference.

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

Closed 2018-11-18.

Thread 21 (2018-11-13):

Label PMOD pins on snap-off board

kbob, 2018-11-13:
Could you please put labels on the snap-off board’s silkscreen saying which PMOD pins are connected to which buttons and LEDs? There’s room on the bottom if you can’t fit it on the top.

esden, 2018-11-18:
Thank you @kbob please review if this is the kind of legend you were looking for. :D

kbob, 2018-11-18:
That works.

Closed 2018-11-18.

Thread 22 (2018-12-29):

RGB LED colours are swapped

miek, 2018-12-29:
Red and blue are swapped on the RGB LED symbol. Red should be between pins 3 and 4, blue should be between pins 1 and 6.

esden, 2019-05-13:
Thank you for pointing this out @miek it is now fixed in V1.0d hardware. :)

Closed 2019-05-13.

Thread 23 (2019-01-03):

PMOD connector 3D model error

DanSGiesbrecht, 2019-01-03:
Hi @esden

I was combing through your design (v1.0c) and noticed that J21 has a duplicated 3D model:

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

esden, 2019-01-03:
The offset model should not show up. The second 3d model is a model from the older KiCad 3d library. You might have both installed. You might want to delete old 3d models and only have the new ones installed. I left the old models just in case and prefixed them with `dis` so that KiCad can't find it. It is strange that it shows up at all. What KiCad version do you have installed?

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

DanSGiesbrecht, 2019-01-03:
Thanks for the quick response! I'm glad to hear that it's just on my end. I have KiCad 5.0.1 installed, with the default 3D library.

esden, 2019-05-13:
Thank you very much for the contribution. This should now be fixed in all the versions of the board. :)

madding1602, 2023-06-14:
Hi. I'm trying to get the CAD file made for a project. I need the 2 PMOD connectors on the side, plus the RGBLED, FLASH and CRESET (straight male), along woth the 2 5V connectors to the 5V (straight females). How can I add them? I haven't used KiCAD, but when I try to create the STEP file it's created with no connectors (and I've tried multiple versions)

esden, 2023-06-14:
@madding1602 This is not the right place to ask the question. It is bad style to jump onto some other github issue that has nothing to do with your project. You should join the KiCad Discord server and ask there instead: https://discord.gg/xvnRc9EY

That said, if you want the part footprints to export together with the board using STEP, you have to make sure that the part models are also STEP and not WRL. If you have further questions please ask them on the KiCad User Discord server.

madding1602, 2023-06-14:
> @madding1602 This is not the right place to ask the question. It is bad style to jump onto some other github issue that has nothing to do with your project. You should join the KiCad Discord server and ask there instead: https://discord.gg/xvnRc9EY
>
> That said, if you want the part footprints to export together with the board using STEP, you have to make sure that the part models are also STEP and not WRL. If you have further questions please ask them on the KiCad User Discord server.

okay. thanks!

Closed 2019-05-13.

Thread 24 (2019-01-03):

Add via in pad to the USB footprint to anchor the pads better to the PCB

esden, 2019-01-03:
The USB connector is pretty sturdy, but we can make it even better if we add via in pad to the ground pads to anchor the connector even better to the PCB.

cliffordwolf, 2019-01-03:
Haha. I already wanted to propose that but thought it would just show how little I know about design for manufacturing. :)

(Would have been expecting something like reduced yield due to soldering issues because the via is also a heat sink.)

esden, 2019-01-03:
Yes that is definitely a risk. Also the wicking of solder down the via can be an issue. But the pads are pretty large and generously covered with solder paste, and the improved anchor can be worth the risk. I will have to think about it a bit and maybe even make a test board with different footprints and make some force tests. :)

emeb, 2019-01-03:
To prevent solder wicking down the vias you could make the pads larger and put the vias underneath mask, with only the mask opening for the socket contacts per mfg specs.

smunaut, 2019-02-15:
Well I would think that getting the via filled with metal would only help the mechanical strength, but of course you need enough solder on there :p

esden, 2019-05-15:
I am postponing addressing this issue. I somehow doubt that just having VIA will actually increase the adhesion of the copper laminate by a significant amount.

I am testing out footprints with solder retention legs on a separate board. If that works out we will go that route. But that will not happen for V1.0d but 1.0e probably.

esden, 2019-05-15:
One more thing. I have connected the shield pads solidly to the rest of the copper pour. This increases the size of the copper laminate that the footprint is connected to. Remembering how the one board looked like that got it's connector ripped off, the failure point were the thermals connecting the pads to the pour. I hope this will improve the mechanical strength for now.

And as always: be nice to your hardware folks, and don't let it dangle under your feet, so you don't trip. :)

esden, 2021-12-18:
As V1.0e is already produced. And the next version of the board will likely have a USB-C connector. I think this issue is irrelevant by now. So I will close it.

Closed 2021-12-18.

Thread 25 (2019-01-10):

Add Bill of Materials

stv0g, 2019-01-10:
I am currently, working on creating a BOM with MPN's and DigiKey part numbers.
Anyone wants to help?

esden, 2019-01-10:
Please do not do that. It is easy enough for an individual to put the board together. We don't need to make the work for cloners even easier. If you have questions about the Bill of Materials please ask me directly in Gitter, I will be happy to help you out: https://gitter.im/icebreaker-fpga/Lobby

esden, 2019-01-11:
If you want to DigiKey part list I might be able to refer you to someone who might already have one. Will save you time. It might be slightly convenient to have this publicly available, but I am usually available on Gitter and will try to help out anyone who asks in person for their personal use. I hope you understand. :)

Closed 2019-01-10.

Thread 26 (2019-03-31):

Replace diode footprint with SOD−523

esden, 2019-03-31:
Schottky diodes in 0603 package are fairly rare. It would be better to use a more common package. An SOD−523 is similar size to the 0603 package and will fit in the same space we currently have allocated for the diode.

Closed 2019-05-13.

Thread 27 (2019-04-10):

Sync FIFO mode support

smunaut, 2019-04-10:
The current version only allows the async fifo mode wit the ftdi to be used. But the async mode is pretty slow. You can pretty much get the same throughput as just using the SPI mode.

The sync interface however is _much_ faster. But of course, needs more pin ....

What I'd suggest :
 * Make the clock input solder jumper configurable between the 12 MHz (current option) and the sync fifo clk out (60 MHz).
 *  Re-use one of the flash pin (like WP#) for the missing OE# signal.

(both with solder jumper with a default config of what's there currently).

daveshah1, 2019-04-10:
I think the sync FIFO interface is only available on FTDI port A. So a bit more shuffling of pins would be needed, quite possibly moving the programming interface to port B (or deal with the collision with the flash). This was discussed early on, but moving the programming port was rejected at the time as it would break compatability with Diamond Programmer and anything else hardcoded to port A. I'm not sure how big an issue this is in practice though.

smunaut, 2019-04-11:
Arf yeah you're right, I hadn't noticed that.
That pretty much kills this idea :/

(1) Moving the programming port isn't a good idea, that would break compatibility with other revision of the icebreaker. Unless you add an eeprom to differentiate VID so it can be handled automatically but then it's added BOM cost and require initial programming (and board space)

(2) Sharing port A would require a bit of external logic (to handle CS# and Reset# which are the two pins that can't be shared) which again, BOM cost and board space.

Unless someone sees another solution, I'd just close this.

kehribar, 2019-05-10:
Hi all,

I was the one who suggested that full PortA should be connected to the FPGA if anyone wants to use higher speed data transfers. See the twitter thread: https://twitter.com/ihsankehribar/status/948182497556357120

Keyword is '245 async FIFO'  and since it is async, implementation is much more easy. Also it can coexist with the JTAG interface. Downside is you get 1/5 of the max usb speed (~40Mbytes/sec) which is around 8Mbtyes/sec. Also, another _problem_ is that the users have to solder zero ohm jumpers to make the additional connections between FPGA and FTDI chip.

I didn't get involved in the crowdsupply campaign for _reasons_ and don't have the icebreaker hardware. Therefore, I didn't do any real work on the topic but I'm sharing the information anyway.

Best,
ihsan.

esden, 2019-05-15:
I have removed the V1.0d milestone from this. I don't think there is a good clean way of swapping the FIFO interface in the short term.

I think a high speed USB interface is something we will have to explore for V2.0 using the FTDI replacement further down the road. So I am keeping this open for now. We will have to see what we can do later.

For those wondering and checking this issue out. We did not want to put the programming on the second channel as it is usually not the default in the programmer software out there. This is an educational board and any special treatment necessary for the board is higher priority issue than one extra jumper feature for power users. We try to accommodate power users as much as we can but we will not compromise the ease of use for the beginner to do that.

Closed 2020-06-25.

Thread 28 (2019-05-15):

Change the AUX CS jumper to Normally Closed

esden, 2019-05-15:
The AUX CS jumper can be closed to connect the first FTDI channel (used normally for bitstream flash or FPGA SRAM programming) to the FPGA Red LED pin. This jumper allows us to stream SPI data into the FPGA resuing the programming port after the programming is done.

One current example using this system is driving LED panels using the @smunaut  [rgb_panel design](https://github.com/smunaut/ice40-playground/tree/master/projects/rgb_panel). Also the project [SLED out_mpsse_spi module](https://github.com/shinyblink/sled/) supports this protocol and can be used as a data source.

Several of us have now used our iCEBreakers with the jumper set, and it does not seem to interfere with any normal operation of the board even if not in use. To make things easier for the users that want to quickly play around with LED panels we should change the NO jumper to NC. This will allow for separation of this connection if some issue appears down the road.

smunaut, 2019-05-15:
The only downside I could see is if some programmer software out there puts that pin as output and doesn't release it after the fpga is configured.

esden, 2019-05-15:
Agreed, I guess we will have to put it out there and see what happens. But we should probably test with the vendor programmer software ourselves to see if it is an issue with the tools we can think of or not.

esden, 2019-05-16:
I have tested the board in Radiant Programmer. It seems to work fine. I call it good and I have changed the jumper to normally closed.

For reference on Radiant settings I have quickly added screenshots to the wiki: https://wiki.icebreaker-fpga.com/wiki/Getting_started

Closed 2019-05-16.

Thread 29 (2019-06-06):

Solderpaste V1.0d for C32, C33 and RBG LED

tinyledmatrix, 2019-06-06:
Is there no solder paste on C32, C33, C34 and the RGB Led on purpose?  According to the top solder paste Layer they should not get covered with solder paste

esden, 2019-06-06:
Yes that is intentional, as they are DNP or optional. Should be marked in the schematic accordingly.

Closed 2019-06-06.

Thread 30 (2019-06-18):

Extend pads of RGB led foot print a bit to make hand solder easier

smunaut, 2019-06-18:
Since it's not populated and is designed for user adding it, making it easier to solder with just an iron is probably a good idea.

Closed 2019-06-30.

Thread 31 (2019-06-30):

Fix ice40 model name in schematic

esden, 2019-06-30:
The schematic states we are using the ice5lp4k that is obviously wrong. We are using ice40up5k.

Closed 2019-06-30.

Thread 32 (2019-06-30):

Fix ice40 RGB schematic symbol pinout

esden, 2019-06-30:
I made a mistake when transcribing the pinout of the ice40up5k to the schematic symbol. The RGB2 should be RGB1 and vice versa.

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

Thanks to @arturo182 for pointing it out. ;)

esden, 2019-06-30:
Fixed in b990430c73aa2a1b76302898bf2e65f9a76230b7

Closed 2019-06-30.

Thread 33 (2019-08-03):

icebreaker-fpga shipped with Pmods need assembly hints

csylvain, 2019-08-03:
if nothing else, adding the image below to the 'img' directory and the Readme will help. time to start the Wiki?
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

Jan-NiklasB, 2019-11-13:
Also the LED-Panel PMod needs some, since it changed from pin-headers to a connector with orientation.

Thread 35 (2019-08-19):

Consider adding suggested part numbers for suitable RGB leds to the doco

TomKeddie, 2019-08-19:
Am looking to add an RGB led but want to be sure I'm ordering something suitable.

Perhaps [150352M173300](https://www.digikey.ca/product-detail/en/wurth-electronics-inc/150352M173300/732-11999-1-ND/8557209) is suitable?  Will be happy to add this to the wiki once we have some confirmed part numbers.  Thanks.

esden, 2019-08-25:
Hey @TomKeddie,

The part that the footprint is designed for is the [CLX6F-FKC](https://www.digikey.com/products/en?keywords=CLX6F-FKC) from Cree. I have bought and used  [CLX6F-FKC-CKNNQDGBB7A363](https://www.digikey.com/short/prq27j)  before with success. I have not compared the footprints but I bet other vendors make RGB LED in compatible packaging. Let us know how it goes.

Cheers,
Piotr

TomKeddie, 2019-08-31:
Here is a photo of the cree part loaded, pin 1 is blue cathode and is oriented towards the B pin.
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

Closed 2019-08-31.

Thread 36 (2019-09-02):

Need to document the user hacks.

kbob, 2019-09-02:
It would be good to add a section on hardware hacking. Here's what I know of.

The WS2812 ear requires two 10K resistors in 0603 packages and a BSS138 MOSFET in SOT23 package. And a header.

The RGB LED pad fits a Cree CLX6F LED.

You can piggyback a QSPI RAM chip onto the flash chip and bring the CS pin out to the nearby pad. The suggested part is Lyontek LY68L6400. It is available from lcsc.com. The datasheet is here. http://esp32.de/lyontek/pSRAM/LY68L6400_0.3.pdf

esden, 2019-10-24:
Thanks, the pull-up value for the WS2812 ear should probably be 1K as described in #37 :)

smunaut, 2020-05-24:
Maybe create a wiki page here and then add a link to it in the readme ?

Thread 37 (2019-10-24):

Fix the schematic to adjust WS2812 ear resistor values

esden, 2019-10-24:
According to @jgmcc42 the 10K pullups are to weak for WS2812 protocol. They should be 1K.

This should be fixed in the schematics and the docs.

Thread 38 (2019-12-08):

Frequency accuracy of the 12 MHz oscillator (U7)

andrsmllr, 2019-12-08:
What is the frequency accuracy of the 12 MHz oscillator (U7) on the Icebreaker board?
The schematic does not define the part number, is a BOM available somewhere?

andrsmllr, 2019-12-08:
OK, so the part name is in fact available in the Kicad project (of course). But the information is still not sufficient to determine the oscillators ppm rating, since the exact part name is not given.
The part is a SiT2001, which is listed here https://www.sitime.com/products/mhz-oscillators#cat226.
The complete part number should look like this "SiT2001BI-**S2**-18E - 25.000025D" and the Sx part denotes the frequency stability (1=+-20ppm, 2=+-25ppm, 3=+-50ppm).
I could not find the complete part number anywhere in the repository, my question therefor remains the same.

esden, 2019-12-08:
Hi @andrsmllr and welcome to the iCEBreaker community. :)

Thank you for your question. The oscillator that we are mounting on the iCEBreaker is the SIT2001BI-S2-33E-12.000000G. This means it is the +-25ppm version.

I hope this helps.

Cheers,
Piotr

Closed 2019-12-08.

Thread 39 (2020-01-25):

Seamless integration of ICEbreaker to Arduino IDE (using soft core)

Harvie, 2020-01-25:
Hello. I saw several projects aiming to integrate softcore to Arduino IDE in a way that the FPGA can then be programmed in C quite easily without much user setup.

For example the lattuino project:
http://fpgalibre.sourceforge.net/Lattuino_en/index.html#tp2
https://github.com/INTI-CMNB/Lattuino_IP_Core
https://github.com/INTI-CMNB/AVR_for_iCE40_IP_Core

Or the FPGArduino:
http://www.nxlab.fer.hr/fpgarduino/
https://github.com/f32c/f32c

Do you think, you can provide such support for icebreaker board? (doesn't need to be AVR, might as well be RISC-V)

I fully understand the difference between programming FPGA in HDL and programming softcore in C. But i think such integration would be great showcase for beginners who come from arduino world to slowly ease into FPGA...

Thanks for considering this.

mithro, 2020-01-25:
If using C (or Rust, or MicroPython) on an iCE40 FPGA is attractive to you, you might want to checkout the Fomu workshop @ https://workshop.fomu.im - a lot of the work there could be easily ported to the icebreaker as they have the same FPGA too.

esden, 2020-01-27:
@Harvie thank you for asking. This is indeed on my radar. Having RISC-V Arduino is definitely something I would like to see for the iCEBreaker.

I did ask people would like to see as an example repository for the iCEBreaker:
* Twitter: https://twitter.com/esden/status/1221873800507080704?s=20
* Discord: https://chaos.social/@esden/103556867287942113

I think the first thing to do is to have some C/C++ Make examples available. But essentially all other environments are somewhat related and can be derived from that. Especially if we build the register files from SVD descriptions.

That said I will eventually get to Arduino. But if you want it faster and want to create an example repository yourself I am very happy to take a look at it and add it to the organization.

Cheers,
Piotr

drtrigon, 2021-11-08:
There is also: https://github.com/drtrigon/fpgarduino-icestorm

It is actually working already and does it's job quite well. I built an Arduino project using it: https://github.com/drtrigon/sketchbook/tree/master/Alhambra-picorv32_AirQuality

The point where I stopped development was while setting up `micros()` as I had issues getting delays on the microsecond level, all I was able to accomplish was about 10-20us. It seems to be related to the memory used on the Alhambra 2 board. The solution I came up with was to add a PLL and speed-up from the clock of 12MHz. But I am not sure whether that would help and also I guess I would need to have a clock of about 120MHz and I doubt that will work - but I did not test it yet!
(for more details see e.g. https://github.com/cliffordwolf/picorv32/issues/126)

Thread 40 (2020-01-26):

"J20 Flash" header - add single-row PMOD option?

fm4dd, 2020-01-26:
Would it be possible to re-arrange the "J20 Flash" header? Shift IO0-3 pins two positions right, add a 3.3 pad next to SCK, and move GND left would give one more single-row PMOD option. I haven't fully checked the board design yet, here is a quick picture of what I mean:

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

Moving CS / SCK to the outer-right, and using their pads as 3.3 / GND would also achieve it.

fm4dd, 2020-01-27:
Never mind, I looked at the schematics. The pins are FTDI IO and not FPGA. All FPGA pins are already brought out.

esden, 2020-01-27:
You are partly correct though. These IO pins go to the FLASH and after the FPGA is configured they could theoretically be used to talk to another device. You just have to be "careful" what you are connecting and how.

The actual issue that I would have with changing the pin order is backwards compatibility. There are plans to make hats for the iCEBreaker that connect to different pins to implement a variety of different features using more than just two Pmod. Changing the position and layout of the pins is pretty much out of the question unless it can be left backwards compatible to the current layout.

Closed 2020-01-27.

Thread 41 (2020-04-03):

FPGA Pin numbers of SPI IO0/IO1 on the diagram are swapped

smunaut, 2020-04-03:
The pinout on https://raw.githubusercontent.com/icebreaker-fpga/icebreaker/master/img/icebreaker-v1_0b-legend.jpg is wrong for the SPI header.  FPGA pin number for IO0 and IO1 are swapped.

mcerveny, 2023-01-11:
I depends on soldered jumpers.
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

smunaut, 2023-01-11:
Yes, obviously but it makes sense to reflect the default configuration. Anyone doing manual alteration on the board has to know what they're doing ...

Closed 2022-06-17.

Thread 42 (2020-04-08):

Too much load on the SRAM slave select line on the bitsy

vr2045, 2020-04-08:
This is wrt the bitsy:

LEDG is hooked up to the SRAM slave select. The FPGA IO can source 4-8 mA at most.

If I read the schematic right, LEDG is hooked up to this same signal that has an LED & 330 ohm resistor which will take up about 8mA to run.

This may work at slow speeds but will potentially have very slow fall time when selecting the SRAM.

You may want to consider increasing the LED series resistor from 330 ohms to 1K or so to allow sufficient drive from the FPGA.

esden, 2020-04-08:
I think you are looking at it wrong. The LED is hooked up to 3v3 not to GND. Also it is just the CS that does not have such high speed requirements as the other pins.

vr2045, 2020-04-08:
Quite possible I misunderstood the schematic.

In my understanding, when the CS to the SRAM is pulled low to activate the SRAM, this will light up the LED and also enable the SRAM at the same time, right? Will consume about 8mA through the LED reducing edge rate of the signal considerably.

When disabling the SRAM, you dont have a problem as the LED+resistor will be the strong pullup.

smunaut, 2020-05-24:
So :

(1) With the led Vf of 2V, the current is only about 4 mA
(2) The UP5k IO are rated for 8 mA _min_. Experiments show they'll drive twice that with no issues whatsoever
(3) I've driven the PSRAM at 147 MHz ... can't go much faster than that ... and the edge rate on CS on the scope is no different than any other IOs.

Closing since both the theory and reality agree that this works just fine.

Closed 2020-05-24.

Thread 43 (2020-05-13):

SPI flash and FT2232H signal contention during the USB enumeration process

Disasm, 2020-05-13:
Steps to reproduce:
1. Build and flash:
```
git clone https://github.com/Disasm/icebreaker-litex-examples
cd icebreaker-litex-examples
git checkout serv
git submodule update --init
cd soc
./icebreaker.py --cpu-type serv --cpu-variant standard --sys-clk-freq 12000000
iceprog soc_basesoc_icebreaker/gateware/top.bin
cd ../r-riscv-blink
cargo run --release
```
2. Unplug the board.
3. Plug the board back with the same cable.
4. Observe that it blinks for a while and then stops blinking.

You can also plug it slowly to connect USB power first and connect USB data lines in a few seconds. Then you can observe that the firmware works until you insert the connector to the end. Also when you use "charging only" USB cable, the issue doesn't happen and the firmware works all the time.

I tried to investigate the issue with a logic analyzer and found that SPI data lines are pulled up for a short period of time (about 2.7ms) during the USB enumeration process.
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
This behavior can be reproduces with a more simple setup.
I used an FTDI breakout board (FT2232H Breakout Board from Dangerous Prototypes) and hooked a 10k resistor between GND and ADBUS2. I chose ADBUS2 because it corresponds to the IO1 signal on iCEBreaker and this signal had the most distortion among others. The EEPROM on this breakout board was empty, so I flashed it with the configuration from my iCEBreaker board. When I captured signals from ADBUS2 and EEPROM lines (EEDATA, EECLK, EECS) I found exactly the same glitch on the ADBUS2 line: instead of being low all the time, it goes high for about 2.7ms. This time interval coincides with a long EEPROM read burst. If I erase the EEPROM, this read burst disappears and the glitch does not happen.

smunaut, 2020-05-13:
The other contentions I have noticed are :
 - When the EEPROM is not configured one of the line is driven constantly (can't remember if it's from boot or only after one iceprog cycle ...)
 - After running iceprog, the reset line is released and the fpga configures but the data lines are still being messed with for a tiny amount of time. This doesn't seem to prevent the fpga from configuring because it overpowers it at "low speed", but when trying to run the flash at high speed (100+ MHz) the signal is too damaged and it makes it unreliable.

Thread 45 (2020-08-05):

Wrong part number

fnsangiul, 2020-08-05:
The 93C46B-SOT-23-6 IC VCC is rated at 5V. The correct version for 3V3 is the 93**L**C46B.

AnasMalas, 2024-11-27:
What part is actually used on the board?

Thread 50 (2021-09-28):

Icebreaker v1.0e -- diodes D1 and D11 are shorted

71GA, 2021-09-28:
I was playing with an SPI and found out that sometimes there is a glitch immediately after data has been sent. There is an entire discussion about this [here](https://electronics.stackexchange.com/questions/587984/ftdi-libmpsee-unreliable-spi-connection).

After checking out the PCB we found out that:

- diode D3 is in a short circuit! Therefore during SPI communication a lot of signals will drop to approx 2.5 V instead of 3.3 V and possibly FPGA resets because of the high current through the LED. If you can... remove the D3...

- Now check the D11... None of the channels from this RGB LED have resistors!!! Luckily the connector D11 is empty, but this is pure luck... Don't ever solder anything there...

What was the hardware designer thinking?

gatecat, 2021-09-28:
I can't see the problem with D3? `CDONE` is an open drain output from the iCE40.

and there are no resistors for D11 because the iCE40 has a built in constant-current sink driver on those pins (`SB_RGBA_DRV`)

71GA, 2021-09-28:
Is there any way to help clear out the things at the link that I posted. SPI is really acting strange. We are out of ideas.

smunaut, 2021-09-29:
Are you trying to talk to the FPGA itself (slave config mode) or some of your own logic loaded on the FPGA ?

In the first case, you need to change the board wiring, by default it's not wired for that ... SI/SO need swapping and the flash needs to be disconnected. You also need to assert the FPGA reset line

In the second case, you're using the wrong chip select line, this will conflict with the flash.

esden, 2021-12-18:
Have you made any additional tests @71GA ? I think some of your understanding and assumptions regarding the circuitry might be wrong. We are using the FTDI SPI interface in many different modes and have not observed issues that you are describing.

In your original description you say that for example 1v2 rail comes up after 3v3 which should not be possible because 3v3 has quite a big startup delay added on the EN pin.

I am having a hard time understanding what exactly you are trying to do. As @smunaut mentioned, you should clarify how you are trying to use SPI in your particular case. Are you trying to write data into a running FPGA, or are you trying to use the SRAM programming mode? So we still need to get on the same page before we can consider trying to resolve your issue.

Maybe we will be able to help if you try to boil down your original question a little bit? Especially now that you have learned a few more things of how the circuit is working. :)

smunaut, 2022-06-17:
Closing as there is obviously nothing wrong ....

Closed 2022-06-17.

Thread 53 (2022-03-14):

Add COPI/CIPO legend to schematics

esden, 2022-03-14:
It is not always clear for everyone what COPI/CIPO stands for.

* COPI: Controller Out Peripheral In (used to be MOSI)
* CIPO: Controller In Peripheral Out (used to be MISO)

This should be added to the schematics to avoid ambiguity.

For additional information refer to the [OSHWA resolution](https://www.oshwa.org/a-resolution-to-redefine-spi-signal-names).

esden, 2022-03-14:
It was brought to our attention that there is a [new resolution](https://www.oshwa.org/2022/01/10/new-spi-terminology/).

So in the process of documenting the change in the schematics it would probably be a good idea to switch to the new order:
* PICO: Peripheral In Controller Out
* POCI: Peripheral Out Controller In

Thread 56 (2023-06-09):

Power input and external pins?

madding1602, 2023-06-09:
Hello everyone. I'm going to start working with an FPGA of this kind in September, and I wanted to know if there is any external power pins to keep the board on without USB cable, and what is the power input consumption from the board. TIA

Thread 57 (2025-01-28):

No Documentation for iCEBreaker v1.1a

CrashAndSideburns, 2025-01-28:
I recently purchased an iCEBreaker v1.1a board from [the 1 Bit Squared shop](https://1bitsquared.de/products/icebreaker), but unfortunately I cannot seem to find any kind of documentation or pinout for the board. I checked [the iCEBreaker FPGA docs page](https://docs.icebreaker-fpga.org/hardware/icebreaker), but the page only seems to have pinouts for older versions of the board, which seem to have several differences from the v1.1a revision. In particular, I do not know which pins on the FPGA are attached to the new PSRAM chip, or how the pins on the ears of the board are connected. I was also hoping to use the FDTI FIFO interface for more efficient communication with a host computer than simple UART would allow, which the documentation shows was possible on revision v1.0b of the board simply by bridging a few pads on the underside of the board, but it appears that these pads are no longer the same on revision v1.1a. I hoped to simply check the schematics to see for myself which pins on the FPGA are routed where, but this repository does not seem to contain schematics for this newest revision of the board.

frohro, 2025-06-10:
I noted schematics on this site now, but I don't see PCB design files for any but the Bitsy.  Are those not to be released?

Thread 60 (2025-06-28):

Questions About USB Interface on iCE40UP5K

hardik1975, 2025-06-28:
I’m new to FPGA development and currently designing a custom board using the iCE40UP5K.
To keep costs low, I’m considering a USB interface like the one used in iCEBreaker Bitsy instead of the FT2232H.

I had two quick questions:

1. In the Bitsy schematic, USBN and USBP are connected to IOT_50B and IOT_51A—can other differential pairs be used?
2. Does the USB interface require a bootloader? If yes, how can I build and flash it?

Thanks in advance! Your work has been super helpful.

bendelathouwer, 2025-07-18:
"Does the USB interface require a bootloader? If yes, how can I build and flash it?" IRC the bootloader would be flashed via a jtag programmer . also check this page out. It meantions it uses RISC-V soft-core USB bootloader](https://github.com/no2fpga/no2bootloader (https://github.com/no2fpga/no2bootloader)

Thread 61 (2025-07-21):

Board file or EasyEDA footprint

SparkyNZ, 2025-07-21:
I cannot seem to find a .brd file for the PCB layout of the iCEBreaker. What I'm hoping to do is making a daughter board that I can attach the iCEBreaker to so it will connect to my existing chain of PCB modules (like a daughter/motherboard for the iCEBreaker to plug into).

Would it be possible to add a .brd file or upload a footprint to EasyEDA please?

I can probably figure one out myself once my iCEBreaker arrives - just trying to be proactive and perhaps an EasyEDA footprint could benefit the community.

dragonmux, 2025-07-21:
You might need to use an older version of KiCad to start with if trying to load older versions of the board, but the board files are KiCad files. The current v1.1a hardware (which is what you'll get) is in modern KiCad format though and can be opened with KiCad 9 just fine.

SparkyNZ, 2025-07-22:
Thanks for your help. I'll close the issue.

Closed 2025-07-22.

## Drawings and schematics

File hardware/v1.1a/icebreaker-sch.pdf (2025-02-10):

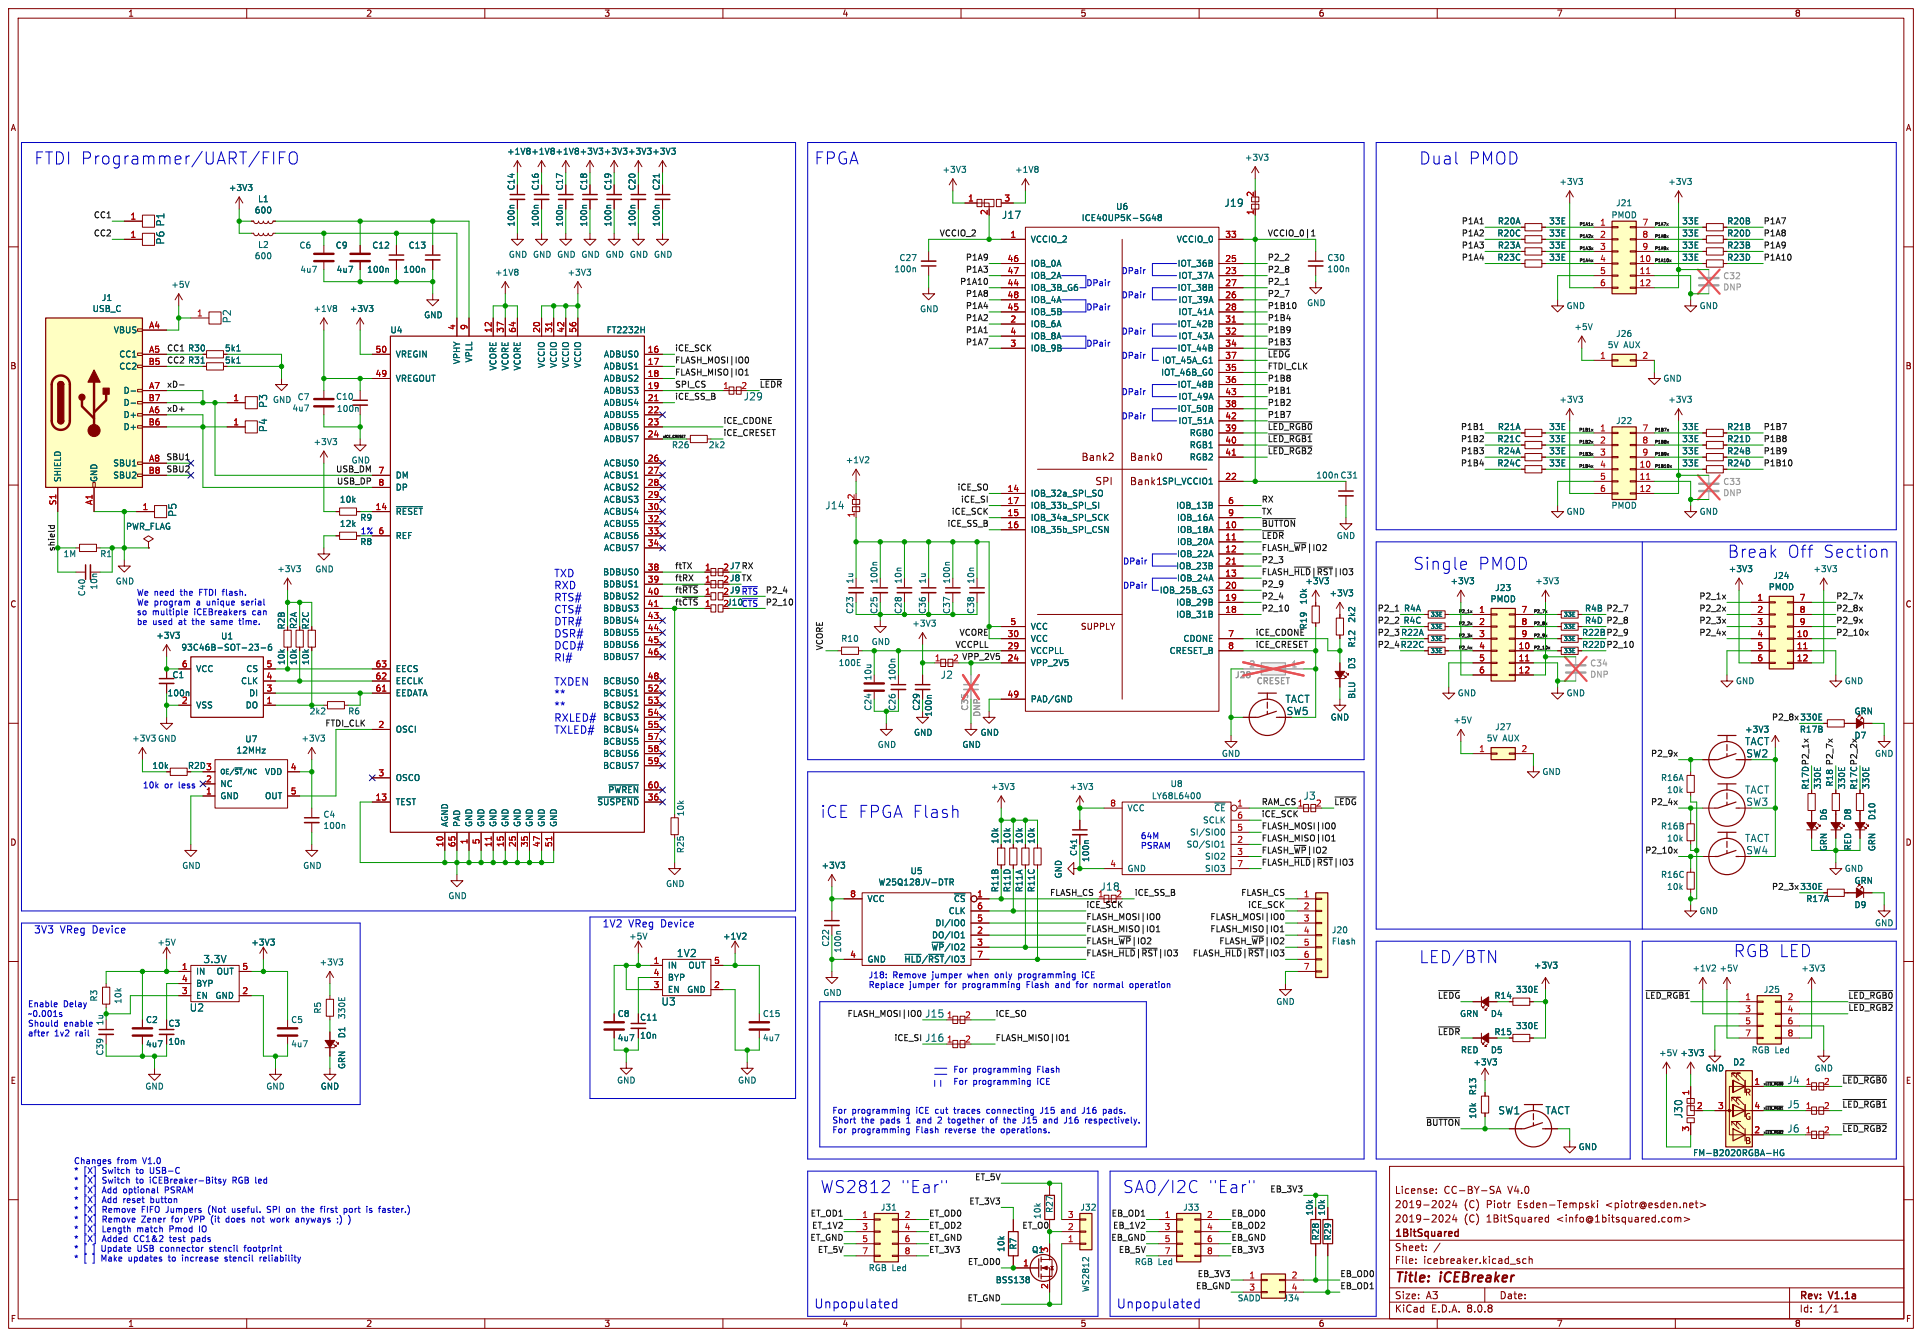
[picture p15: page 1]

PSRAM FTDI Programmer/UART/FIFO

1 AGND 10 GND 11 VCORE 12 TEST 13 ~{RESET} 14 GND 15 ADBUS0 16 ADBUS1 17 ADBUS2 18 ADBUS3 19 OSCI 2 VCCIO 20 ADBUS4 21 ADBUS5 22 ADBUS6 23 ADBUS7 24 GND 25 ACBUS0 26 ACBUS1 27 ACBUS2 28 ACBUS3 29 OSCO 3 ACBUS4 30 VCCIO 31 ACBUS5 32 ACBUS6 33 ACBUS7 34 GND 35

4 BDBUS2 40 BDBUS3 41 VCCIO 42 BDBUS4 43 BDBUS5 44 BDBUS6 45 BDBUS7 46 GND 47 BCBUS0 48 VREGOUT 49 GND

5 VREGIN 50 GND 51 BCBUS1 52 BCBUS2 53 BCBUS3 54 BCBUS4 55 VCCIO 56 BCBUS5 57 BCBUS6 58 BCBUS7 59 REF 6 ~{PWREN}60 EEDATA 61 EECLK 62 EECS 63 VCORE 64 PAD 65 DM 7 DP 8 VPLL

after 1v2 rail 3V3 VReg Device

Enable Delay ~0.001s Should enable

Changes from V1.0
* [X] Switch to USB-C
* [X] Add reset button
* [X] Remove FIFO Jumpers (Not useful. SPI on the first port is faster.) * [X] Remove Zener for VPP (it does not work anyways ;) ) * [X] Length match Pmod IO

Id: 1/1 Title: iCEBreaker File: icebreaker.kicad_sch Sheet: / 1BitSquared

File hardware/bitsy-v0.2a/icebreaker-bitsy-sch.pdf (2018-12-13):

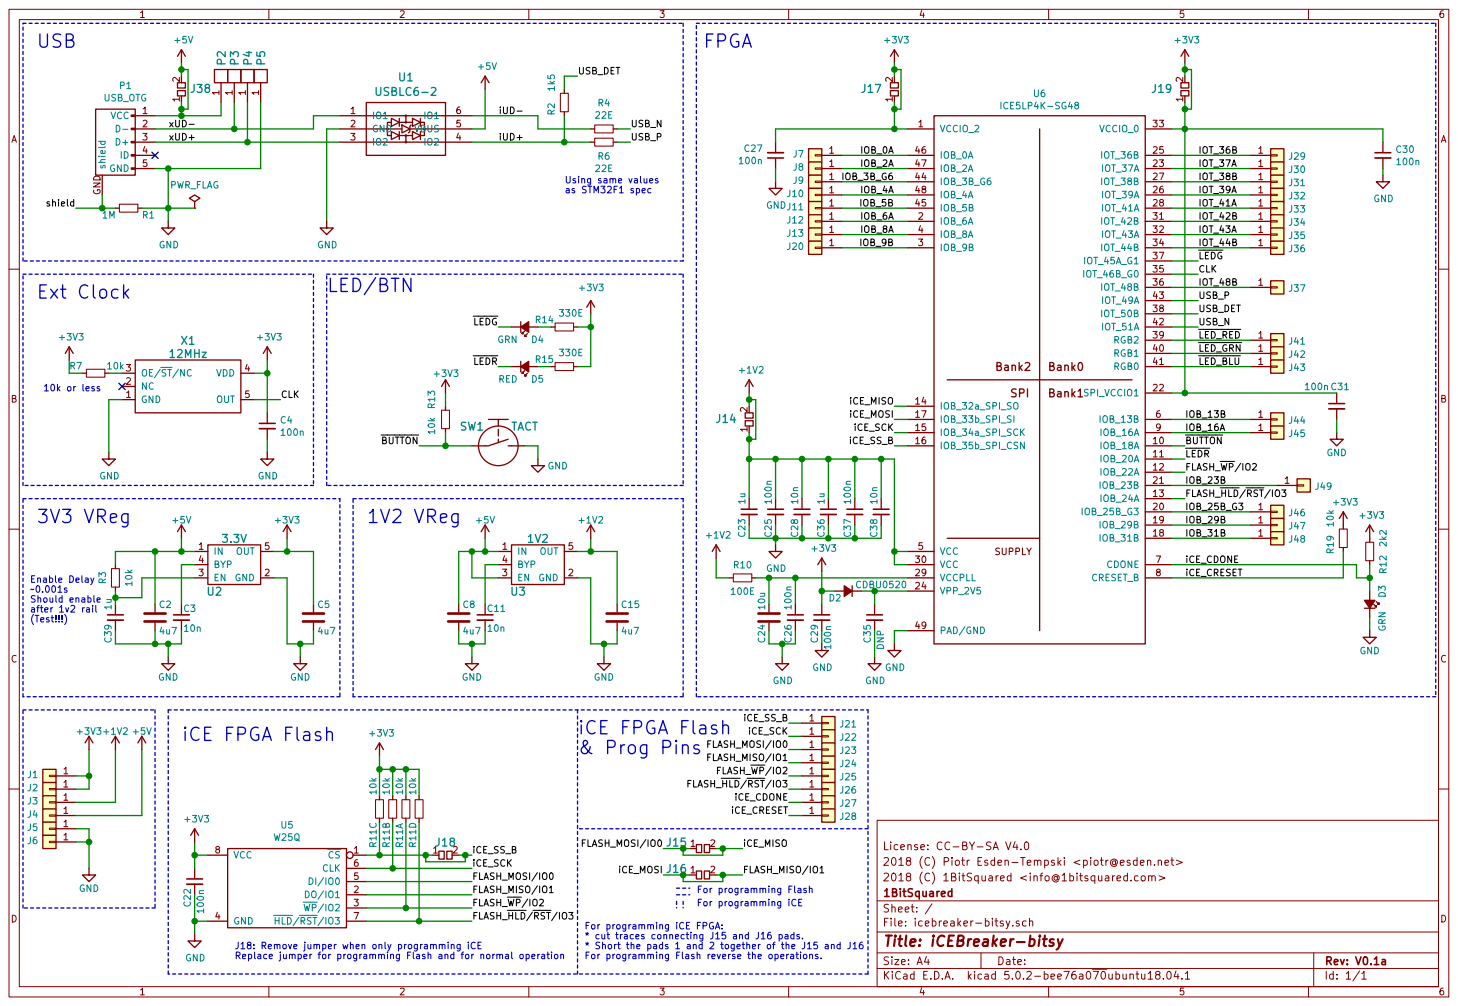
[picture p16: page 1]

LED_GRN 1
LED_BLU 1

Enable Delay 0.001s Should enable

2018 (C) Piotr Esden-Tempski <piotr@esden.net>
2018 (C) 1BitSquared <info@1bitsquared.com>
File: icebreaker-bitsy.sch Sheet: / 1BitSquared

Id: 1/1 Title: iCEBreaker-bitsy

For programming iCE FPGA:
* cut traces connecting J15 and J16 pads.
* Short the pads 1 and 2 together of the J15 and J16
For programming Flash reverse the operations.

J18: Remove jumper when only programming iCE

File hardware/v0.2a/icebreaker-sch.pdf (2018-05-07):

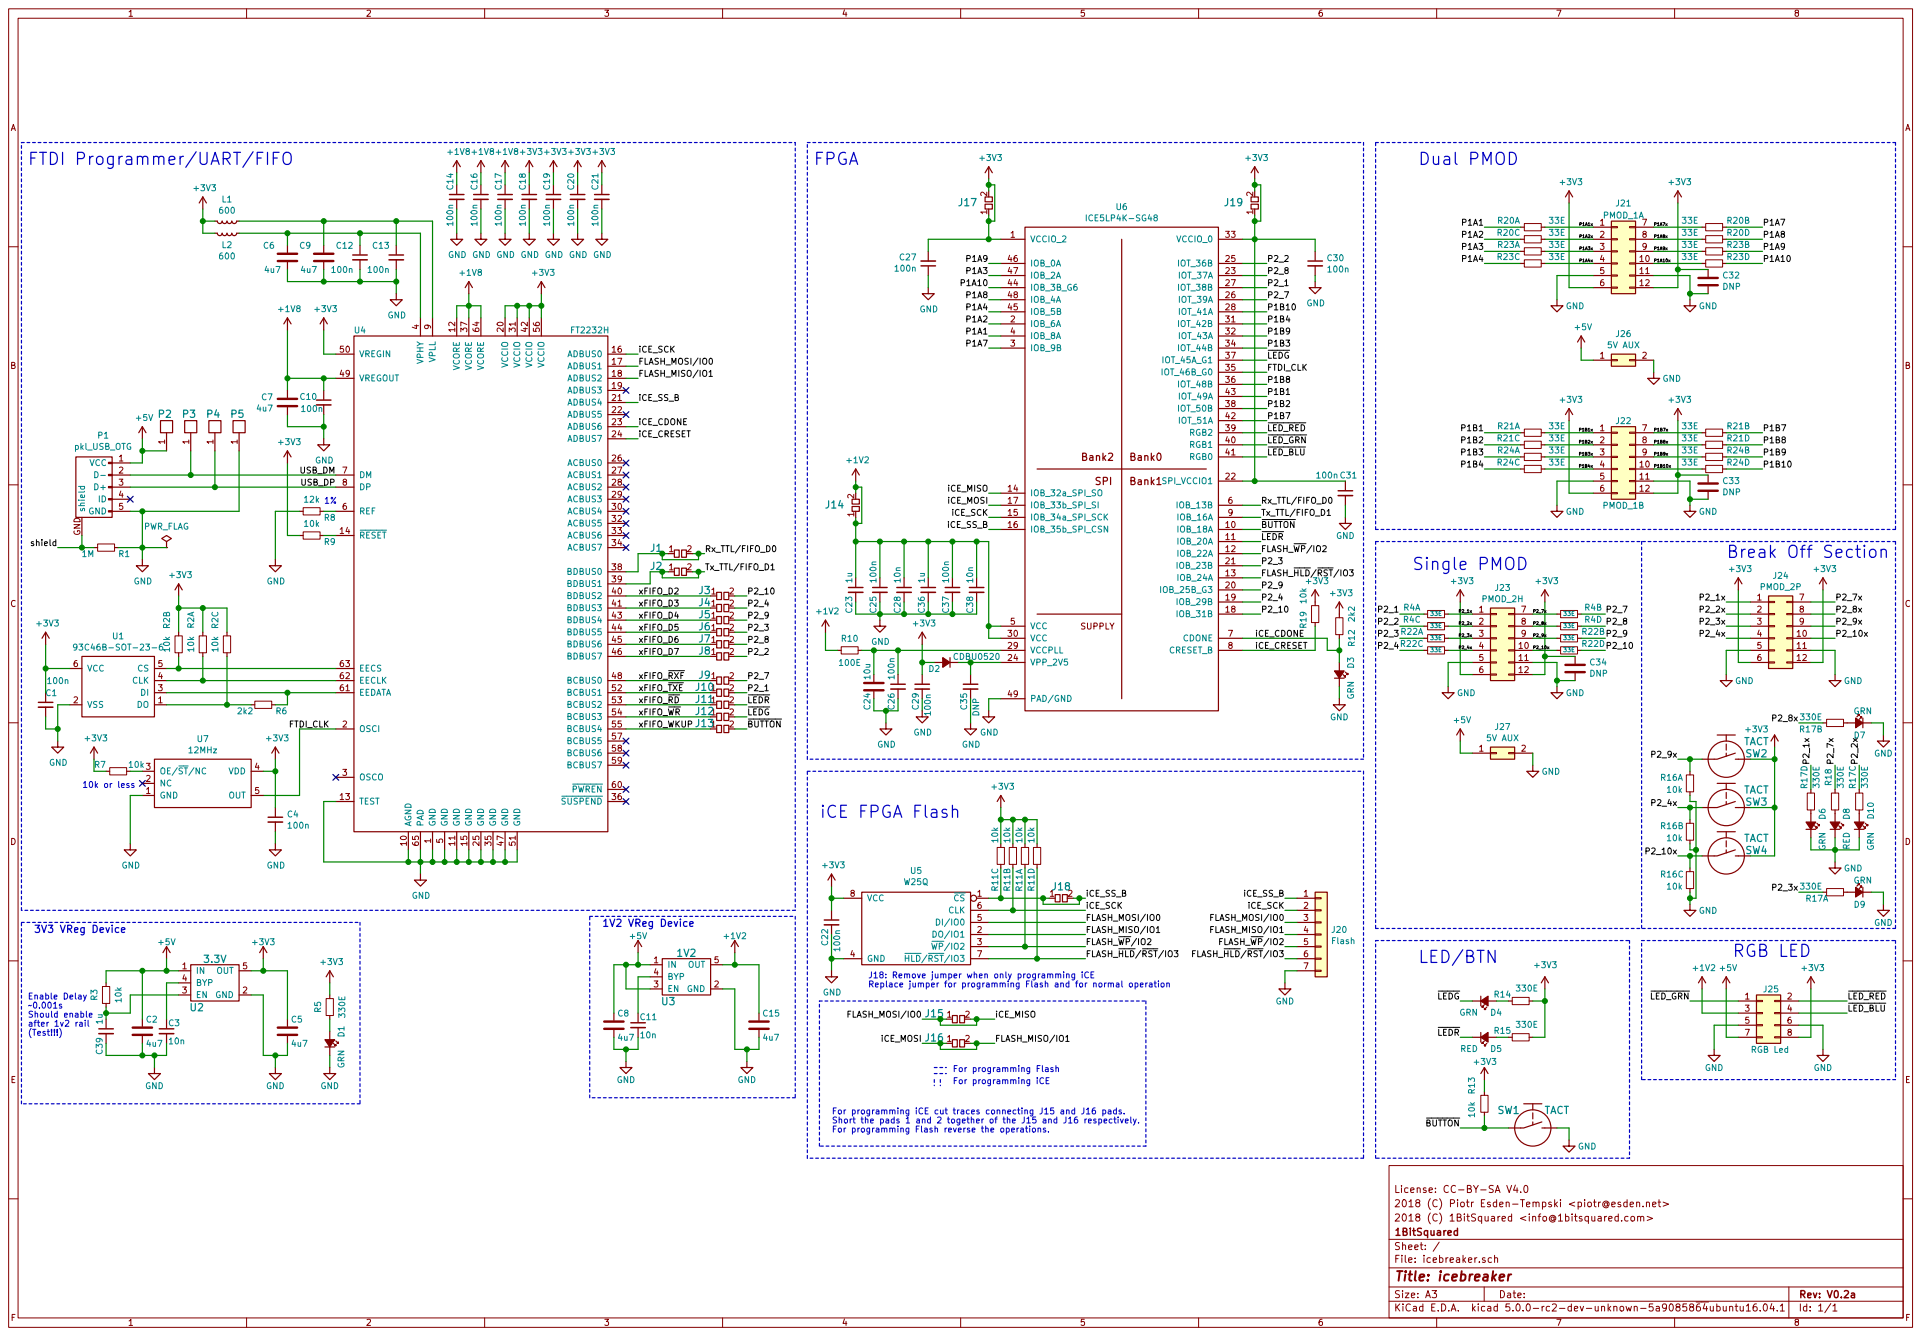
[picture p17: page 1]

LED_RED FTDI Programmer/UART/FIFO

1 AGND 10 GND 11 VCORE 12 TEST 13 RESET 14 GND 15 ADBUS0 16 ADBUS1 17 ADBUS2 18 ADBUS3 19 OSCI 2 VCCIO 20 ADBUS4 21 ADBUS5 22 ADBUS6 23 ADBUS7 24 GND 25 ACBUS0 26 ACBUS1 27 ACBUS2 28 ACBUS3 29 OSCO 3 ACBUS4 30 VCCIO 31 ACBUS5 32 ACBUS6 33 ACBUS7 34 GND 35 SUSPEND 36 VCORE 37 BDBUS0 38 BDBUS1 39 VPHY

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

J18: Remove jumper when only programming iCE

Enable Delay 0.001s Should enable

For programming iCE cut traces connecting J15 and J16 pads.
Short the pads 1 and 2 together of the J15 and J16 respectively.
For programming Flash reverse the operations.

License: CC-BY-SA V4.0
2018 (C) Piotr Esden-Tempski <piotr@esden.net>
2018 (C) 1BitSquared <info@1bitsquared.com>
Id: 1/1 Title: icebreaker File: icebreaker.sch Sheet: / 1BitSquared

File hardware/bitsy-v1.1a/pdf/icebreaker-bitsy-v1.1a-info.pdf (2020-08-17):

# iCEBreaker Bitsy v1.1a

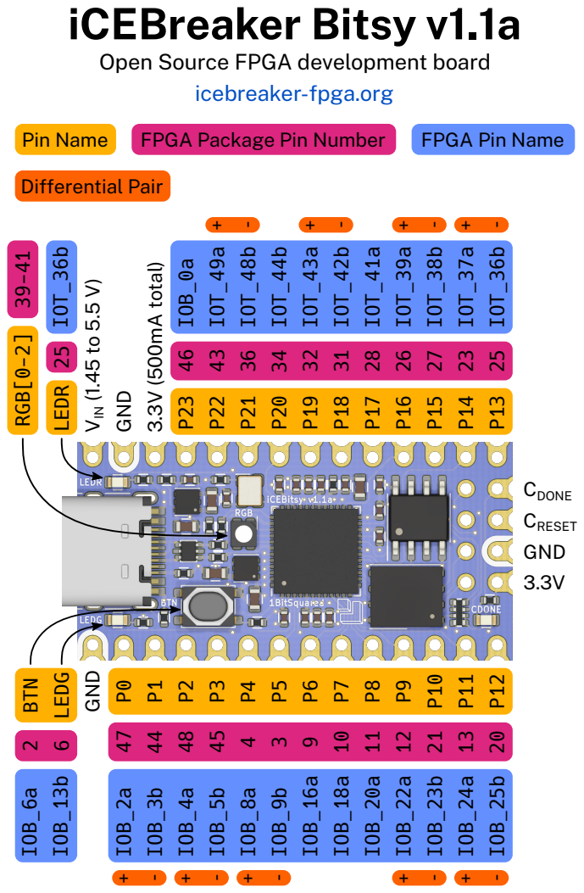
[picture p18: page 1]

Open Source FPGA development board

# iCEBreaker Bitsy v1.1a

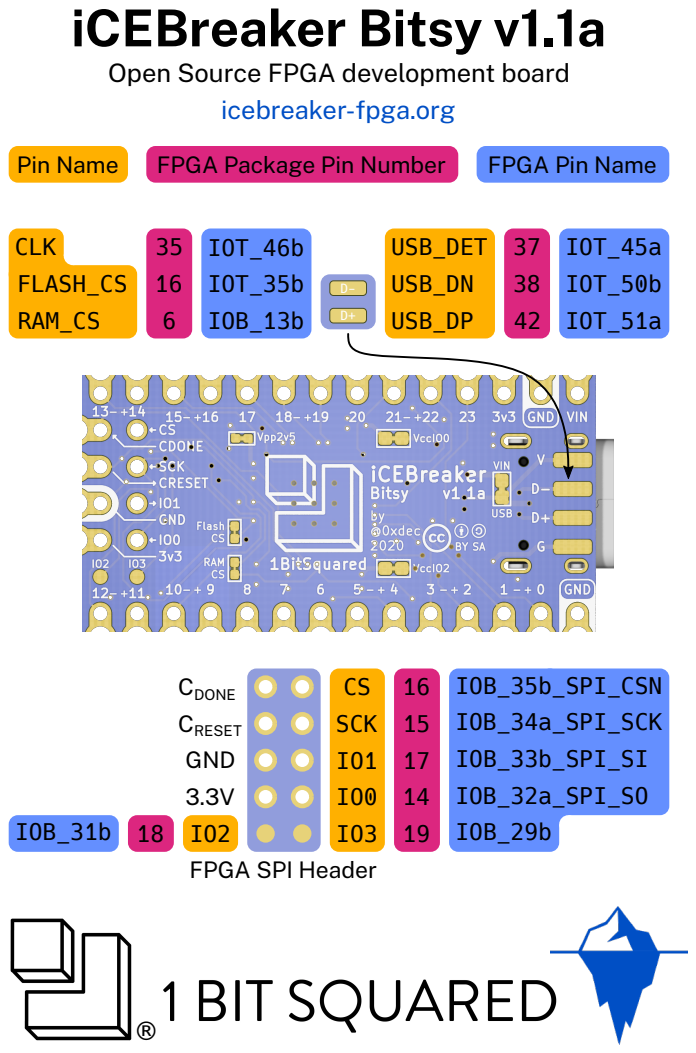
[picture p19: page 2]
Pin Name; FPGA Package Pin Number; FPGA Pin Name; CS SCK IO1 IO0 IO3; IOB_35b_SPI_CSN IOB_34a_SPI_SCK IOB_33b_SPI_SI IOB_32a_SPI_SO IOB_29b; GND; CRESET; CDONE; IOB_31b; USB_DN USB_DP; USB_DET; CLK; IOT_50b IOT_51a; IOT_46b; IOT_45a; FLASH_CS 16 IOT_35b; RAM_CS; 6 IOB_13b

Open Source FPGA development board

icebreaker-fpga.org

FPGA SPI Header

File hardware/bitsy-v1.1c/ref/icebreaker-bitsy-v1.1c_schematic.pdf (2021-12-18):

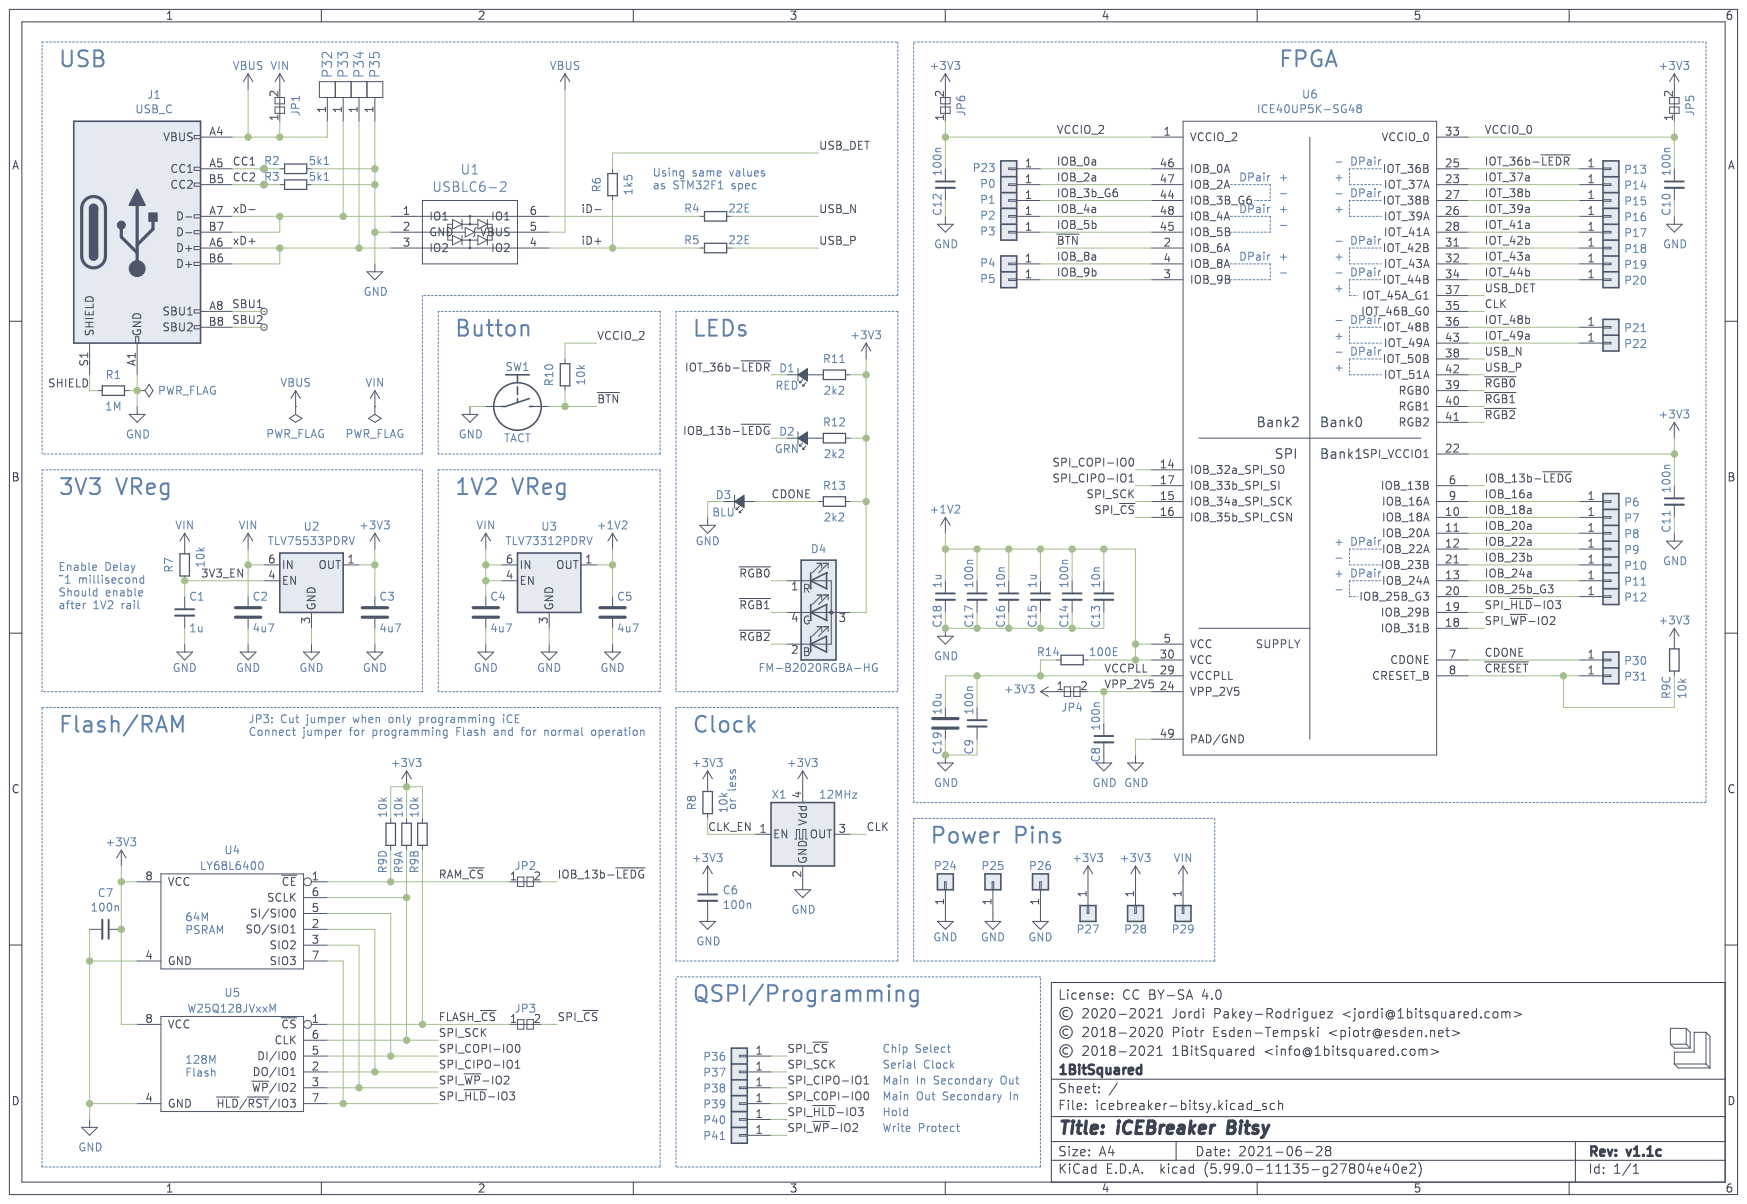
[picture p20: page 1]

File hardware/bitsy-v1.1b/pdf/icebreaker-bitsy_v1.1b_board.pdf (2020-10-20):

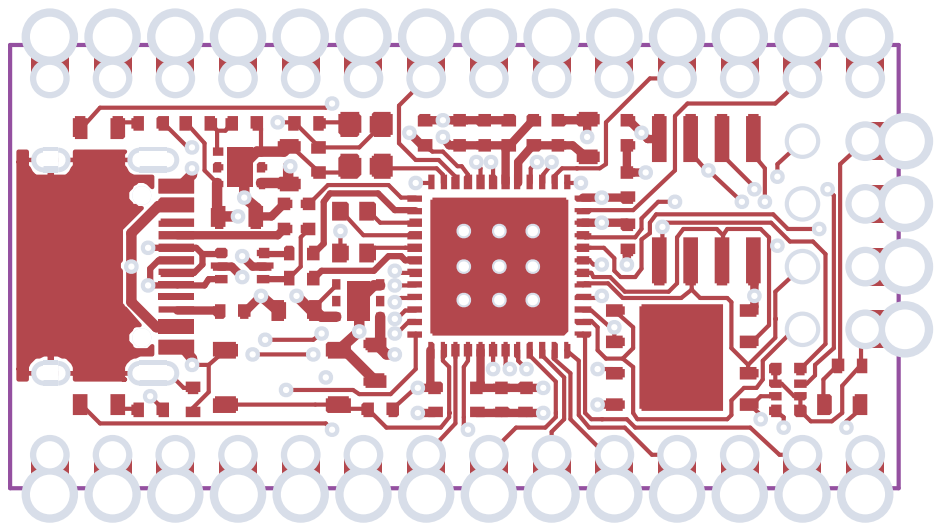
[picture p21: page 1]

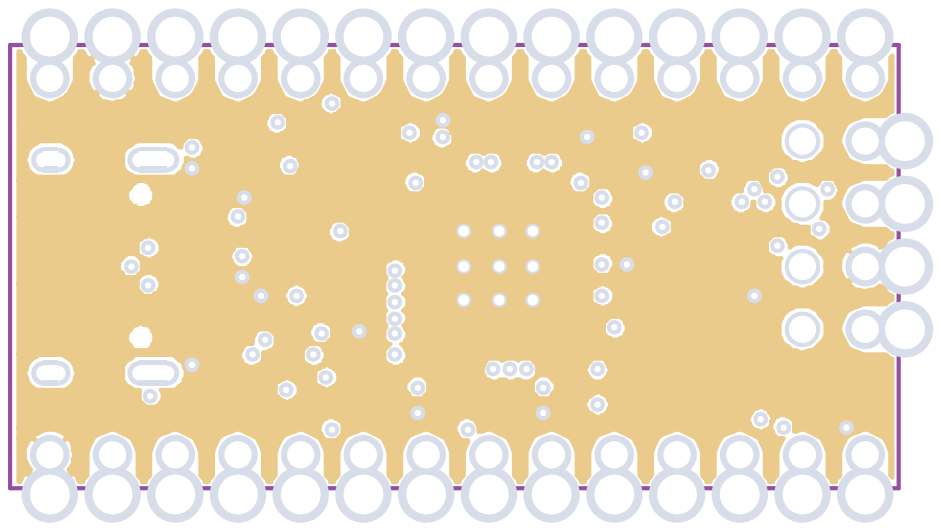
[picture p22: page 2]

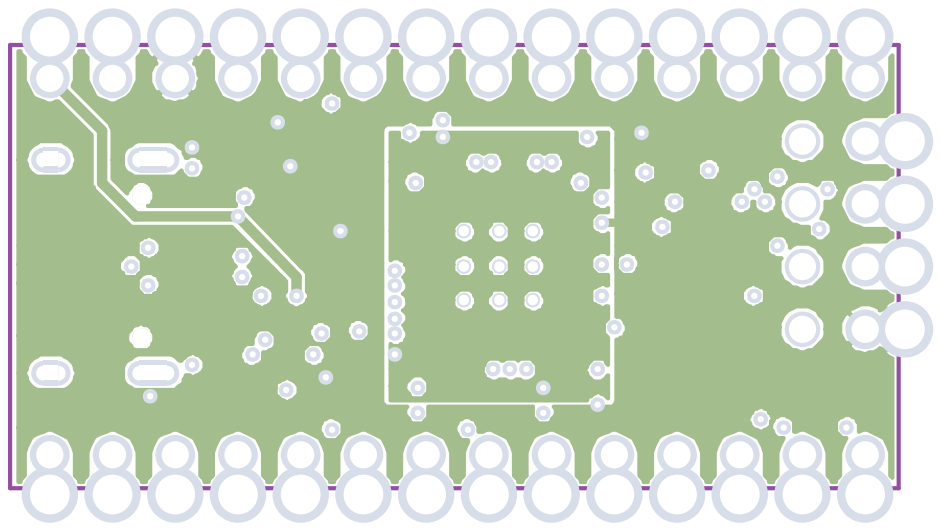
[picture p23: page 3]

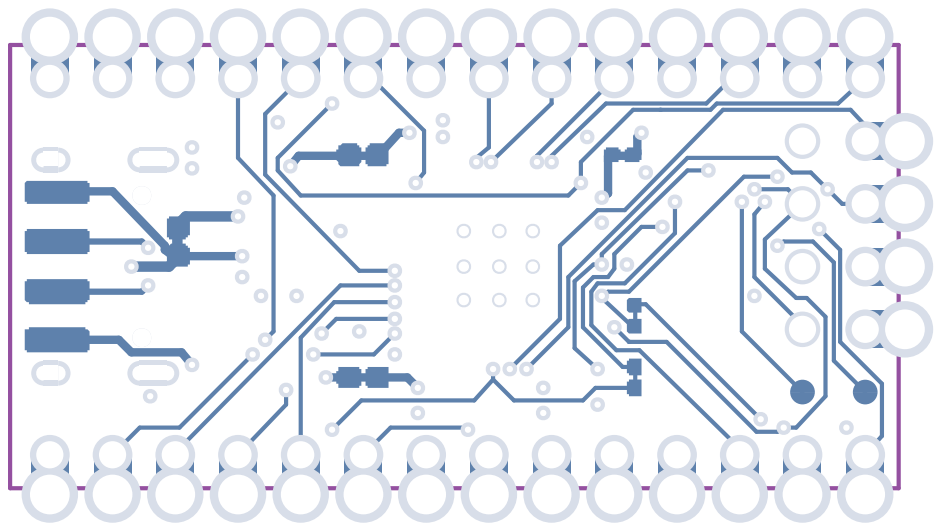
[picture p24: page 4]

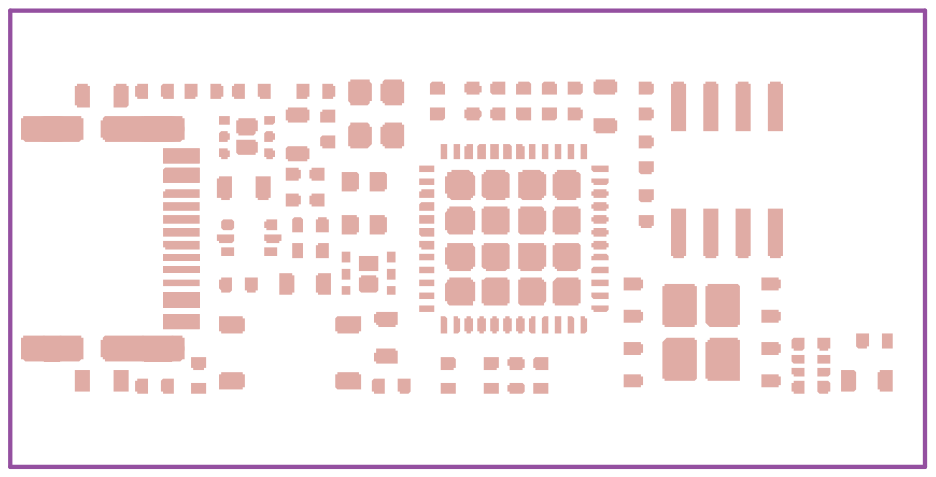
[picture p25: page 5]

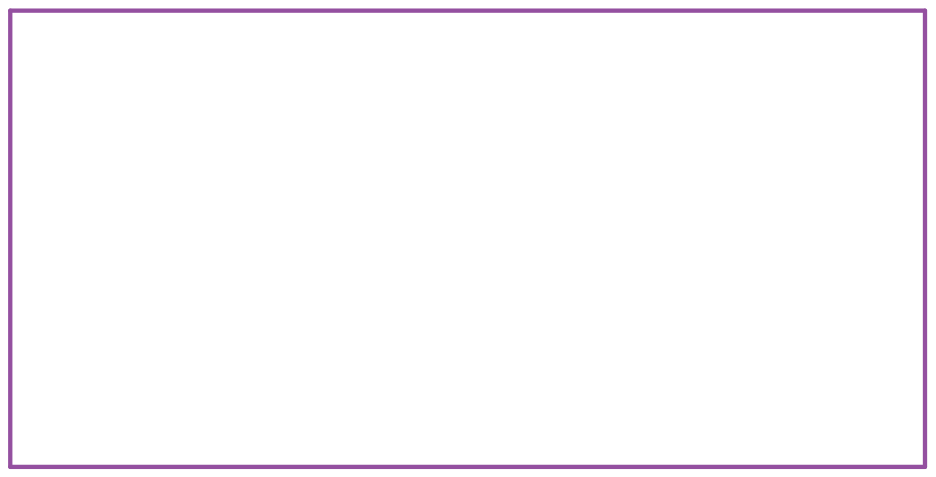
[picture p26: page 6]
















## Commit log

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2018-01-08 Fixed 100E to be 10k pullup on the user button.
    [icebreaker.sch]
2018-01-08 Changed the second decoupling cap on FTDI 1v8 VREGOUT to 4u7.
    We need bulk capacitance on that rail. That was a copy pasta mistake.
    Credit goes to to Kevin Hubbard for pointing this out. :D
    [icebreaker.sch]
2018-01-08 Added AUX 5V for dual PMOD and PMOD bulk capacitance footprints.
    To support PMOD that want to regulate their own voltage from raw USB 5V
    we have an additional header between the PMOD. (based on the idea used
    by PMODs by Kevin Hubbard thanks @blackmesalabs :D)
    Added footprints for optional bulk capacitance for the PMOD power pins
    thanks @mubes :D
    Also assigned footprints to all the remaining symbols and minor
    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
    [icebreaker.sch]
2018-01-08 Added a footprint for an optional VPP_2V5 decoupling capacitor.
    Thank you for the suggestion @daveshah1 :D
    [icebreaker.sch]
2018-01-08 Initial commit of the board file.
    Basic floor plan and path forward for the actual work. :)
    [icebreaker.kicad_pcb]
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2018-01-12 Gateswapping to improve routing, rough placement of all footprints on PCB.
    Now we have less of a ratsnest of PMOD connections to the FPGA.
    Moved all footprints within the board outline to roughly their
    positions. More reordering will happen, but we are slowly getting a feel
    for how much space we will need on the board. :)
    [icebreaker.kicad_pcb, icebreaker.sch]
2018-01-12 Added missing 10k CRESET pullup.
    Thanks for spotting it @daveshah1 :D
    [icebreaker.kicad_pcb, icebreaker.sch]
2018-01-13 Changed buttons to smaller KMR2, routed breakoff and changed breakoff mechanics.
    Additionally routed the USB connector.
    [icebreaker.kicad_pcb, icebreaker.sch]
2018-01-14 Moved PMOD connectors to be better centered vs metric mechanics.
    Also referenced the 3d model that is part of pkl now instead of my local
    model.
    Added symbols for grounding mounting holes to the schematic. Did not add
    them to layout yet as they need quite a lot of space on the board. Still
    need to decide if we actually will do that. :/
    [icebreaker.kicad_pcb, icebreaker.sch]
2018-01-17 Added more FPGA VCC decoupling.
    The reference designs don't state clearly how much decoupling is needed.
    For good measure I have doubled the amount of decoupling capacitors to
    ensure the 1.2V VCC rail is smooth and stable. Testing will be necessary
    to figure out how much of those caps is actually necessary in the final
    board design.
    Also done a bunch of routing and positioning, moving closer to the first
    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
    [icebreaker.kicad_pcb, icebreaker.sch]
2018-01-17 Added 3v3 vreg enable delay.
    The VCCIO rails should power on after the 1v2 core voltage. To ensure
    that we have an RC delay on the 3v3 vreg enable pin. Need to test in
    real life! :D
    [icebreaker.kicad_pcb, icebreaker.sch]
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2018-01-18 Fixed DRC errors.
    [icebreaker.kicad_pcb]
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2018-01-28 Schematic cleanup and minor improvements.
    Added ESD protection on the USB interface, added +5V VIN Jumper.
    [icebreaker-bitsy.kicad_pcb, icebreaker-bitsy.sch]
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2018-01-29 Adjusted USB resistor values based on Luke Valenty suggestions.
    Thanks @tinyfpga ! :D
    [icebreaker-bitsy.kicad_pcb, icebreaker-bitsy.sch]
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2018-03-05 Fixed #6 Oscillator pinout and schematic symbol.
    Both bitsy and icebreaker.
    [icebreaker-bitsy.kicad_pcb, icebreaker-bitsy.sch, icebreaker.kicad_pcb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]
2018-03-05 Replaced 0402 4.7u capacitors with 0603 for consistency. Fixes #4
    [icebreaker.kicad_pcb, icebreaker.sch]
2018-03-11 Added inline resistors on all PMOD connectors to allow for higher GPIO speeds.
    [icebreaker.kicad_pcb, icebreaker.sch]
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2018-03-11 Two more of 3d models corrected.
    [icebreaker.kicad_pcb]
2018-03-11 Added USB signal pads.
    These pads can be used for testing, debugging as well as hard wiring a
    usb extension cable.
    [icebreaker.kicad_pcb, icebreaker.sch]
2018-03-11 Added USB pads for easier debugging and hardwired USB connection.
    This patch fixes #8
    [icebreaker-bitsy.kicad_pcb, icebreaker-bitsy.sch]
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2018-03-13 Initial commit of the FTDI FT232 breakout.
    This breakout board is meant to be used as a multipurpose tool to work
    and interface with the icebreaker fpga boards and more.
    [ftdi.kicad_pcb, ftdi.sch]
2018-03-14 Changed the ftdi breakout design to use a 50mil header.
    This also decreases the width of the breakout, which will allow us to
    make standard complient 0.8" wide PMOD modules using the breakout board
    as a basis.
    [ftdi.kicad_pcb, ftdi.sch]
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2018-03-16 Updated the SPI PMOD adapter to a full PMOD interface.
    This setup allows the use of the adapter with INT and RST lines too.
    [ftdi-pmod-spi.kicad_pcb, ftdi-pmod-spi.sch]
2018-03-16 Corrected pmod UART pinout and added INT/RST pins.
    [ftdi-pmod-uart.kicad_pcb, ftdi-pmod-uart.sch]
2018-03-16 Fixed PMOD pinout on SPI adapter.
    [ftdi-pmod-spi.kicad_pcb, ftdi-pmod-spi.sch]
2018-03-16 A bunch of minor fixes.
    * PWRSAV instead of WRSAV in signal table.
    * 0.05 solder stop opening instead of 0.2
    * Better copper fill parameters.
    [ftdi-100mil.kicad_pcb, ftdi-100mil.sch, ftdi-bitsy-prog.kicad_pcb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]
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2018-03-16 Corrected parameters for gerber export.
    [ftdi-100mil.kicad_pcb, ftdi-bitsy-prog.kicad_pcb, ftdi-pmod-fifo.kicad_pcb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]
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2018-03-17 Corrected fill on the UART PMOD adapter.
    [ftdi-pmod-uart.kicad_pcb]
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2018-05-07 Added/corrected missing 3d models.
    [icebreaker.kicad_pcb]
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2018-05-09 Removed the ftdi multitool. It is now in it's own repository.
    You can find the ftdi multitool here:
    https://github.com/esden/ftdi-multitool
    [ftdi-100mil.kicad_pcb, ftdi-100mil.sch, ftdi-bitsy-prog.kicad_pcb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]
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2018-09-06 Use normally closed jumpers. And fix VCCIO2 bypass. Closes #11
    These jumpers connect two nets without impacting the schematic net
    lists. This is a safer solution and easier to read than having to
    remember where the net jumpers have to go and not miss a side path.
    These jumpers use a hack of KiCAD where the DRC ignores lines on the
    copper layer in footprints. The two pads of the jumper are shorted
    within the footprint but they are not from the perspective of the DRC.
    While I was already at it I have also replaced / separator with |
    separator for multifunction nets. Unfortunately KiCAD reserves the /
    separator for its multisheet net naming. This patch should fix the
    bypass of the VCCIO0 jumper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
    [icebreaker.kicad_pcb, icebreaker.sch]
2018-09-06 Added pulldown on the B port ~CTS ftdi line. Closes #10
    With this line pulled down we can use minicom even when hardware flow
    control is enabled. If this pin is not pulled low and hardware flow
    control is used, no data is ever sent out by the FTDI chip. This can
    easily happen because minicom has hardware flow control enabled by
    default.
    I decided to only add the CTS line pulldown to keep the placements under
    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
    [icebreaker.kicad_pcb, icebreaker.sch]
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2018-09-06 Add an FPGA CRESET jumper. Fixes #9
    Adding an in line resistor for the CRESET line from FTDI as well as a
    jumper that allows access and pulldown of the CRESET line. This allows
    us to override the CRESET signal from FTDI and force the FPGA chip to
    stay in reset in cases when we need to access the flash and prevent the
    FPGA from configuring the FLASH chip. Especially in cases when the FPGA
    is using the FLASH after the design is loaded and configures the flash
    into QSPI and other higher bit modes.
    [icebreaker.kicad_pcb, icebreaker.sch]
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2018-09-15 Added missing CRESET label on the back of the board.
    [icebreaker.kicad_pcb]
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2018-09-16 Added differential comparator input pin pair groupings.
    The symbol in the schematic now shows which pins form diff comparator
    input pairs.
    [icebreaker.sch]
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2018-10-04 Changed the inline CRESET resestor to 2k2.
    We need a lower resistor value so that the FTDI chip can reset the FPGA.
    Using a 10k resistor results in a voltage divider and the 1.65v is too
    high to assert reset.
    [icebreaker.kicad_pcb, icebreaker.sch]
2018-10-14 Initial commit of iCEBreaker V1.0b.
    * Added 1V8 jumper for FPGA GPIO bank 2. Not added to 0&1 as the pins on
    that bank are also connected to the FTDI chip. Extra precausions have to
    be taken in that situation as the FTDI chip GPIO are connected to 3.3V.
    The user will have to assure that there are no problems and the FPGA
    will not fry either itself or the FTDI chip. We do not want to encourage
    that, but if you feel adventerous you are welcome to try. ;) Closes #15
    [icebreaker.kicad_pcb, icebreaker.sch]
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2018-11-18 Mechanical adjustments, added stabilization cupons and more.
    * Rounded the main board corners to match mouting hole centers
    * Decreased mounting hole size to 3.2mm diameter for tighter fit and
    more edge material.
    * Removed radiusses on the breakoff section tabs and added corner
    drills, to make for an easier and cleaner break.
    * Added (currently blank) coupons in the empty areas around the
    break-off section. This will add stability in shipping and allow us to
    fill the area with hopefully something useful. If not something silly.
    :)
    [icebreaker.kicad_pcb]
2018-11-18 Added jumper from ADBUS3 to ~LEDR. Closes #18
    Thanks for the suggestion @smunaut :D
    [icebreaker.kicad_pcb, icebreaker.sch]
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2018-11-18 Rotated CRESET label correctly.
    [icebreaker.kicad_pcb]
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2018-11-18 Optimized out one 10k placement. Replaced R7 with R2D.
    We had a spare 10k resistor in the quad pack used for FTDI flash
    pullups, we can use that one instead of a discrete separate placement.
    [icebreaker.kicad_pcb, icebreaker.sch]
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2019-05-13 Fixed RGB LED labling. Replaced RGB LED signals to be color agnostic.
    The FPGA does not care which color is connected to which pin, so
    referring to the pins as red, green and blue is bit silly. The signals
    are now RGB0-2 instead. The only place where we label the colors are on
    the actual Cree LED package pins.
    This fixes #22
    [icebreaker.kicad_pcb, icebreaker.sch]
2019-05-13 Fixed pin header 3d models.
    We had some of the models doubled up or not fully disabled. Now the TH
    pin headers are all using KiCad V5 3d model locations and are all
    disabled.
    This fixes #23
    [icebreaker-bitsy.kicad_pcb, icebreaker.kicad_pcb, icebreaker.sch]
2019-05-13 Changed the VPP_2V5 diode footprint to SOD-523.
    The SOD-523 is more common. While I was at it I also named the VPP_2V5
    net.
    This fixes #26
    [icebreaker.kicad_pcb, icebreaker.sch]
2019-05-13 Corrected pads on all the footprints to be roundrect.
    [icebreaker.kicad_pcb]
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2019-05-13 Bumped the revision on the breakoff section.
    Missed that before. :/
    [icebreaker.kicad_pcb]
2019-05-14 Corrected the SAO/I2C ear name in schematic and on board.
    [icebreaker.kicad_pcb, icebreaker.sch]
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2019-05-15 Updated footprints.
    This updates and corrects thermal pad stencil aperture sizes and updates
    QFN pads to roundrect.
    [icebreaker.kicad_pcb]
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2019-05-16 Corrected breakoff/ear corner radiusses.
    [icebreaker.kicad_pcb]
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2019-05-16 Corrected the note about FTDI Flash.
    [icebreaker.sch]
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2019-05-17 A bunch of DRC fixes and improvements.
    [icebreaker.kicad_pcb]
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2019-06-30 Initial commit V1.0e extending RGB led footprint pads.
    Fixes #30
    [icebreaker.kicad_pcb, icebreaker.sch]
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2019-06-30 Corrected the RGB pin numbering.
    The original symbol was based on the older ice5lp not ice40up. The
    numbering/naming of those pins changed. Now it should be fixed.
    Fixes #31 and #32
    [icebreaker.kicad_pcb, icebreaker.sch]
2019-06-30 Corrected one of the ear net names to match the RGB led net changes.
    [icebreaker.kicad_pcb, icebreaker.sch]
2019-06-30 Corrected silkscreen for the RGB connector.
    [icebreaker.kicad_pcb]
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2020-03-28 Replaced/added the null logo to the boards.
    [icebreaker-bitsy.kicad_pcb, icebreaker.kicad_pcb]
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2020-03-31 Finished circuit changes todo items.
    * Replaced the VPP2V5 circuit with just a jumper.
    * Added missing 3d models to the footprints.
    * Replaced MEMS oscillator with a more common type. (might not be final)
    This is the work done during the KiCad Let's play stream on March 29th
    2020.
    [icebreaker-bitsy.kicad_pcb, icebreaker-bitsy.sch]
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2020-04-02 Updated the oscillator footprint and initial routing/cleanup work.
    This is the status after the KiCad Let's Play Twitch stream from Apr 01
    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
    [icebreaker-bitsy.kicad_pcb, icebreaker-bitsy.sch]
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2020-07-06 Swap Eco2 and B.SilkS GND silk
    [icebreaker-bitsy.kicad_pcb]
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2020-08-14 icebitsy v1.1a: Corrected oscillator bom key.
    [icebreaker-bitsy.sch]
2020-08-14 icebitsy v1.1a: Corrected the ice40up5k bom key.
    [icebreaker-bitsy.sch]
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2020-09-09 icebitsy v1.1a: Corrected RGB LED bom ID.
    [icebreaker-bitsy.sch]
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2020-10-20 iCEBitsy v1.1b: Fix grid alignment & finalize board
    [icebreaker-bitsy.kicad_pcb, icebreaker-bitsy.sch]
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
